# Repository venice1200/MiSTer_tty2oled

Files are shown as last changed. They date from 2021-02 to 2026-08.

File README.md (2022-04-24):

## 👾  👾

*A Display Add-on for the **[MiSTer FPGA]**.*

<br>



<br>
<br>
<br>

<div align = right>
  <div align = center>
  
This project provides both the **Hardware** as well as the <br>
**Software** to drive an **OLED** display with your Arduino <br>
with simple **USB** connection to your **MiSTer** system.
  
  </div>
</div>

<br>
<br>
<br>

---

<div align = center>

  **⸢ [Documentation] ⸥**
  **⸢ [Creating Graphics] ⸥**
  
</div>

---
[][License]
<!----------------------------------------------------------------------------->

[Badge License]: https://img.shields.io/badge/License-GPLv3-blue.svg?style=for-the-badge

[Logo]: Pictures/tty2oled_logo_120x46_blue_black.png?raw=true

[MiSTer FPGA]: https://github.com/MiSTer-devel

[Creating Graphics]: https://github.com/venice1200/MiSTer_tty2oled/wiki/Build_GSC_Gimp
[Documentation]: https://github.com/venice1200/MiSTer_tty2oled/wiki
[License]: LICENSE

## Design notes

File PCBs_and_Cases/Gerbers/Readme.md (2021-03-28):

**Gerber files for producing PCB's.**

PCBWay has a very nice online Gerber viewer:
https://www.pcbway.com/project/OnlineGerberViewer.html

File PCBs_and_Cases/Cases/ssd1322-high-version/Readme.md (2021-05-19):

### This is the "high" version for 3.12" SSD1322 displays

If you want an external case for your tty2oled and have used pin headers to stack the display to the PCB's, this should fit your needs.
Inserting the PCBs or the complete setup into the case is a fiddling thing. To counteract this I've glued the 4 spacer to displays and stacking PCB and was able to use the whole thing very easily.

After inserting screw together case and display/spacer, then put up the lid onto case's back. There're two 3mm holes which may be used to screw case and lid together, but this isn't mandatory and you keep easier access to the ESP :wink:

The ZIP archive presented [here](https://github.com/venice1200/MiSTer_tty2oled/blob/main/PCBs_and_Cases/Cases/ssd1322-high-version/MiSTer_tty2oled.zip) contains ready-to-use STL files for using with 3D printers and other rocket science. But if you're interested in remixing, reworking or customising the case or parts of it, there're [OpenSCAD](https://openscad.org) files for this also included.

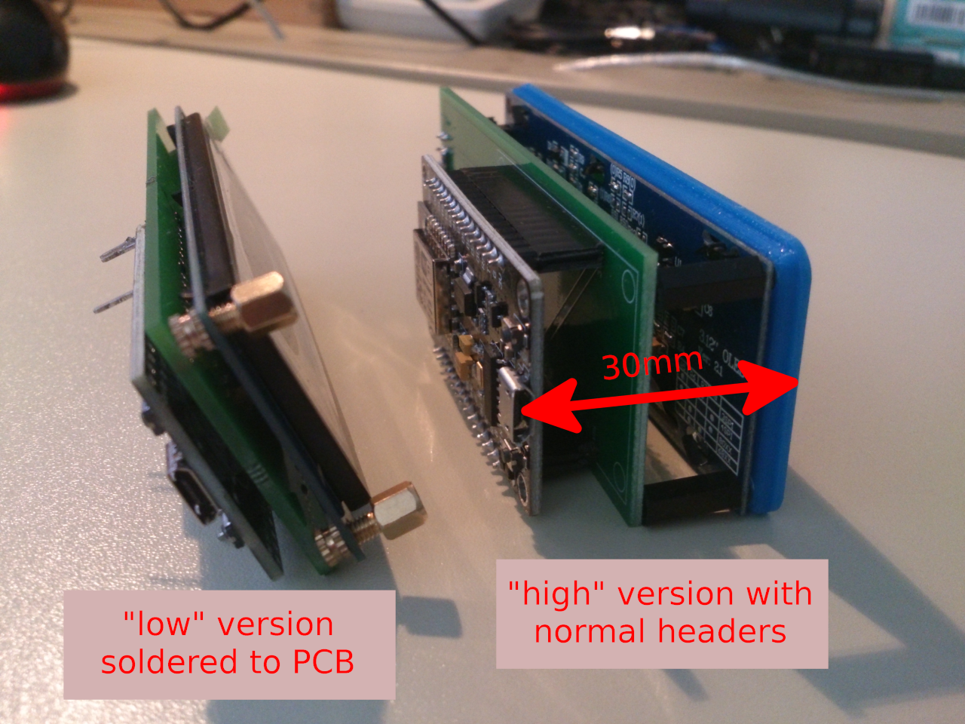
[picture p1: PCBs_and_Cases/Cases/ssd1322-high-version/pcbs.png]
PCBs


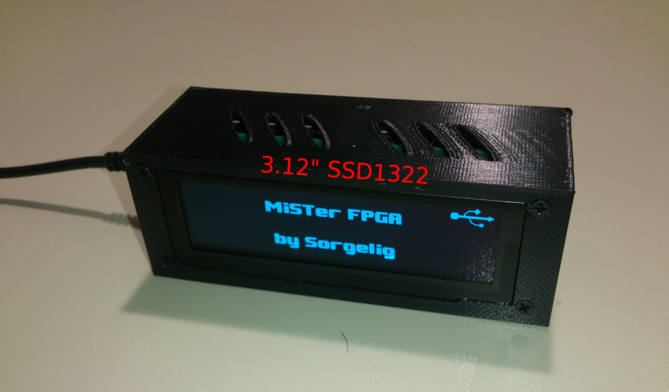
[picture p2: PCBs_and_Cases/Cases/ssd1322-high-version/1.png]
Front


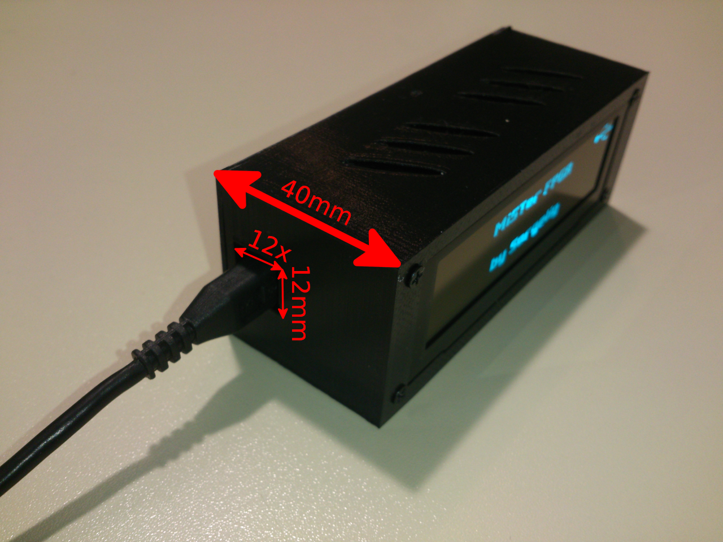
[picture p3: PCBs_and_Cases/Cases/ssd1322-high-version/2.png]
USB side


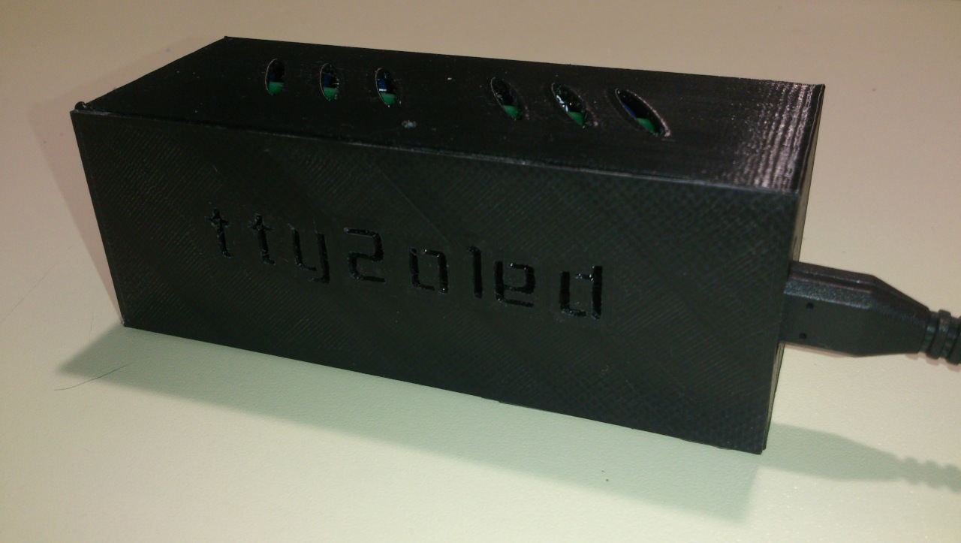
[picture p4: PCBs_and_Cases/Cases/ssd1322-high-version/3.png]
Back


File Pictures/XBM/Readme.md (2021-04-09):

**SD-Version**  
Add your XBM Logo/Picture files to the root folder of your SD Card.  
  
**USB-Version**  
Copy the XBM Logo/Picture files to the `/media/fat/tty2oledpics` folder of your MiSTer's  
or use the new Installer/Updater, see https://github.com/venice1200/MiSTer_tty2oled/wiki/Installation.
  
Name the pictures like the core is named plus .xbm as file extension.  
Example: Lunar Lander's Core Name is "llander", filename must be "llander.xbm".  
The XBM must be 256x64 Pixel for a SSD1322 OLED Display  
  
Examples:  
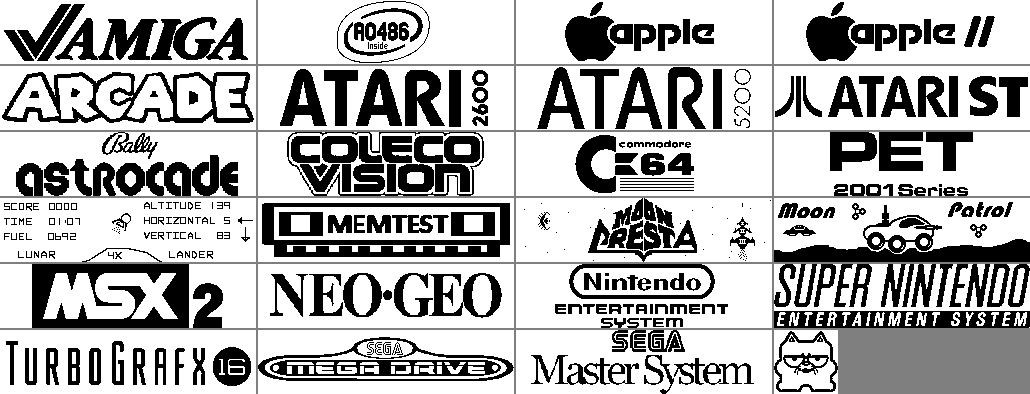
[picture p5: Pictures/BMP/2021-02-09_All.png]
AllInOne


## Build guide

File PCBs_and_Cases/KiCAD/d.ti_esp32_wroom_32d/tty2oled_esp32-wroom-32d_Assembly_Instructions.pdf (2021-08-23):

## Assembly instructions for tty2oled_esp32-wroom-32d case

Required parts:

1x tty2oled_esp32-wroom-32d PCB
1x 3.12“ OLED display (256 x 64 pixel / SSD1322 controller) 1x Case front part
1x Case rear part
4x Standoff (for M3 screws / height: 11 mm)
8x M3 insert nuts (outer diameter: 4.6 mm / length: 6 mm) 4x M3 screws (flat head / length: 20 mm)
4x M3 screws (countersunk head / length: 6 mm)
Step 1: Insert M3 nuts into front and rear part of the case (using a soldering iron).

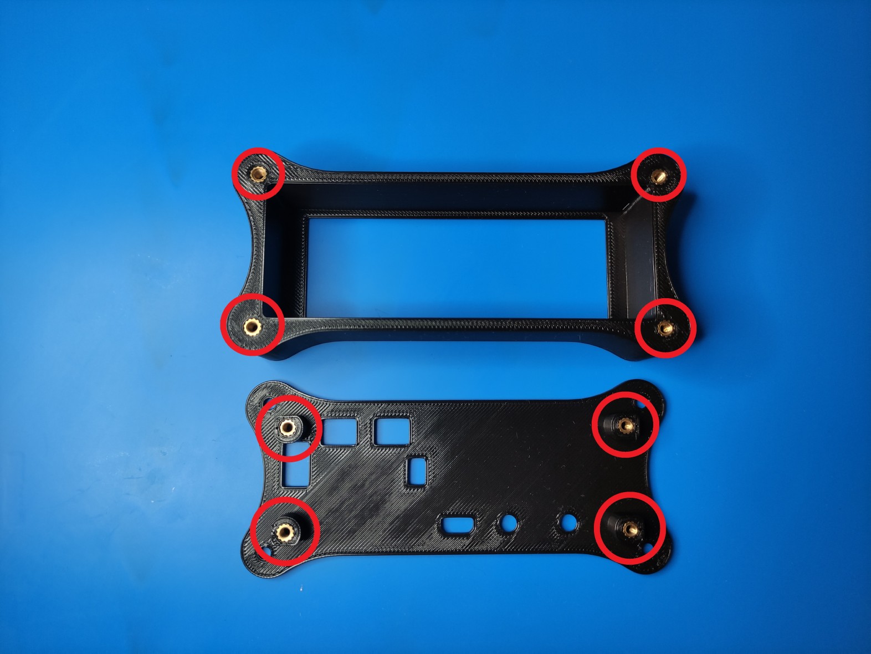
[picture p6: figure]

Step 2: Place tty2oled_esp-wroom-32d PCB on top of the case rear part.
Step 3: Place standoffs on top of tty2oled_esp-wroom-32d PCB.

Step 4: Connect display to tty2oled_esp-wroom-32d PCB.
Step 5: Lock display and tty2oled_esp-wroom-32d PCB into place using M3 flat head screws.

Step 6: Put case rear part onto front part.
Step 7: Lock case rear part to front part using M3 countersunk head screws.

Step 8: Done.

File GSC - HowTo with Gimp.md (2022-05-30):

------------------------ ENGLISH ------------------------

Have a look for a banner or logo of the desired picture which roughly could
be scaled down to 256\*64 pixels without losing too much details and contrast.
Start Gimp, load or insert the found picture and

- if there is a transparent layer, remove it by /Layer/Transparency/Remove Alpha Channel
- /Colours/Desaturate/Colour to Grey
~~- /Colours/Invert~~ Let image2lcd do the invert
- /Image/Mode/Indexed/Generate optimum palette (16 Colours)
- /Image/Scale Image/256\*64 if possible. It might be needful to resize
  the picture non-proportional. Otherwise resize to 256\*Y or X\*64 and
- use /Image/Canvas Size afterwards to move the whole thing so that it fits
- /File/Export as/ and save your work as GIF
- Start image2lcd, load your GIF, check *Reverse color* and save the result as \*.C file
  without "head data"
- Edit the created \*.C file and replace the line
  "const unsigned char gImage_x[8192]" by

//  
//  
const unsigned char _bits[8192] PROGMEM = {

Done.
------------------------ ------ ------------------------
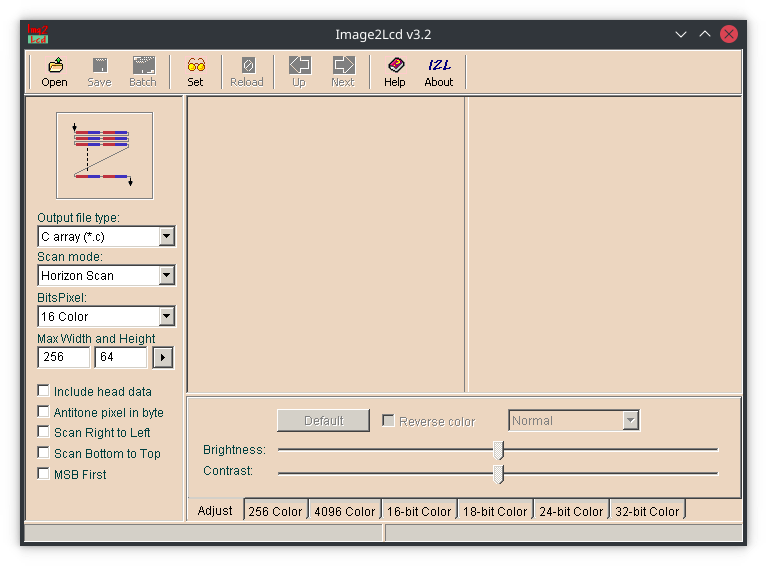
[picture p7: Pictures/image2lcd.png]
image2lcd settings

------------------------ ------ ------------------------

------------------------ GERMAN ------------------------

Ein Banner o.ä. suchen, welches sich Pi\*Daumen auf ca. 256\*64 Pixel skalieren
lässt. Hatt man denn eines gefunden, ist die weitere Vorgehensweise wie folgt:

- Falls eine transparente Ebene vorhanden ist: /Ebene/Transparenz/Alphakanal
  entfernen
- /Farben/Entsättigen/Grau einfärben
~~- /Farben/Invertieren~~ Besser durch image2lcd invertieren lassen
- /Bild/Modus/Indiziert/Optimale Palette (16 Farben)
- /Bild/Bild skalieren/256\*64 sofern möglich. Manchmal reicht es auch, einfach
  nicht-proportional zu skalieren. Ansonsten auf 256\*Y oder X\*64 skalieren und
- per /Bild/Leinwandgröße das ganze zurecht rücken, so dass es passt
- /Datei/Exportieren nach/ als BMP oder GIF speichern
- Das exportierte Bild in image2lcd laden, *Reverse color* anhaken und als \*.C wieder speichern
  (ohne "head data")
- Im \*.C Export die Zeile "const unsigned char gImage_x[8192]" entfernen und
  durch ersetzen durch:

//  
//  
const unsigned char _bits[8192] PROGMEM = {

Fertig.

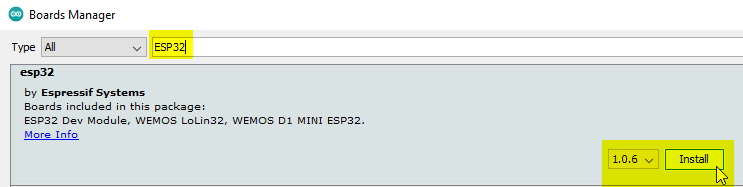
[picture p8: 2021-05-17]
Pictures/HowTo/tty2oled_arduino_03_board_02_ESP32.png

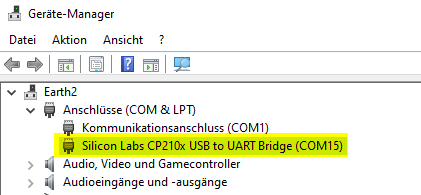
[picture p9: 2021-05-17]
Pictures/HowTo/tty2oled_arduino_10_windows_01_device.png

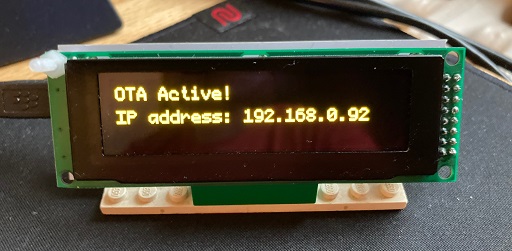
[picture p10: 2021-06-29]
Pictures/HowTo/tty2oled_arduino_14_BasicOTA_03.jpg

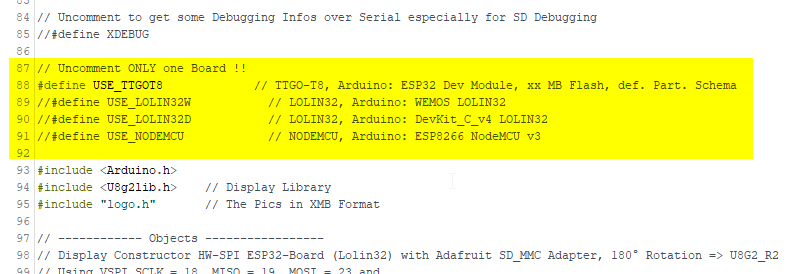
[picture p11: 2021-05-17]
Pictures/HowTo/tty2oled_arduino_07_sketch_01_uncomment_board.png

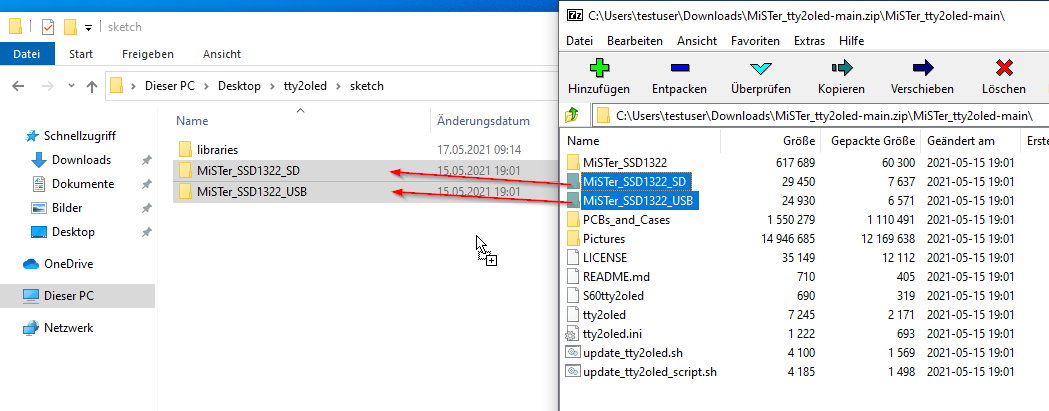
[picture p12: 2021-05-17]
Pictures/HowTo/tty2oled_arduino_05_sketch_01_extract.png

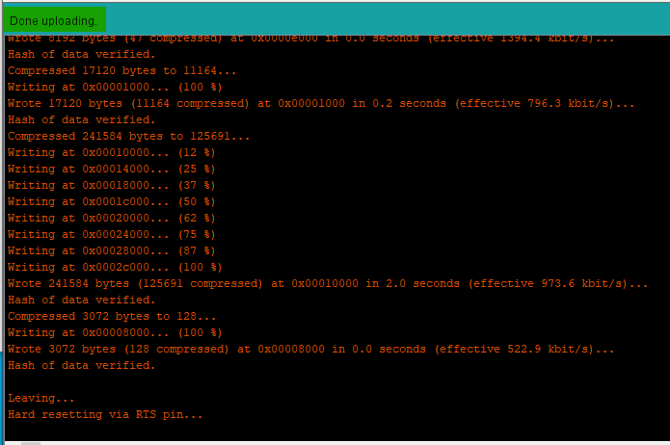
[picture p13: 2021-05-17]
Pictures/HowTo/tty2oled_arduino_12_sketch_03_uploaded.png

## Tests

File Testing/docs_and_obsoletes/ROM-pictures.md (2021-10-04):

Überlegungen zu den neuen ROM-Pictures

Relevant neben /tmp/CORENAME sind /tmp/CURRENTPATH und /tmp/FULLPATH. In CURRENTPATH steht die gestartete ROM-Datei des Cores und in FULLPATH der Pfad zum gestarteten ROM.

Da viele ROMs dieselbe Fileextension haben wie schon andere Cores/ROMs und Dateinamen der ROMs unzuverlässig sind, scheinen Dateiprüfsummen unausweislich.  
Es gibt für viele/alle Emulatoren ROM-Sets, aus denen man entweder eine bereits vorhandene Prüfsummendatei entnehmen (z.B. MAME) oder ggf. eine eigene generieren könnte. Aufbau der Prüfsummendatei für uns ähnlich wie gehabt:

Dateiname des Bilds immer klein ohne Extension, Unterstrich statt Leerzeichen:
__sha1sum[space]Dateiname_des_Bilds_ohne_Extension__
e4134a3b4a065c856802bc935c12fa7e9868110a battlezone  
2bbc124cead9aa49b364268735dad8cb1eb6594f james_bond_007  

(keine Extension weil **first find fits**, also gsc -> xbm -> text)

Parallel dazu einen User-eigenen Prüfsummenteil für persönliche Vorlieben, Homebrews, Hacks .....

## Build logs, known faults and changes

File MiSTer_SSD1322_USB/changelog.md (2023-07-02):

*************************** tty2oled Arduino-FW Changelog ***********************

  2023-07-02
  -Release to Stable

..2023-04-27
  -Cosmetics

  2023-04-20/2023-03-16
  -Add Command CMDSTTYACK to (set) enable(1)/disable(0) sending "ttyack". Enabled by default.
   Using no Command Delay (cDelay) if "ttyack" is not sent.

  2023-01-08
  -Add Boolean "runsTesting"

  2022-12-09..2023-01-07
  -Add more "hasXX"

  2022-12-08
  -Change 8266 NodeMCU Tilt Pin 16 (D0) to Pin 10 (SD3) to prevent false Rotation detection

  2022-11-27
  -Switch dtiv Version handling from "EEPROM" to "Preferences"

  2022-11-23
  -Removed unused Board Types

  2022-11-12..13
  -Add Suport for ESP32-S3 (ESP32-S3-DevKitC-1)
  -Removed OTA Support
  -Add EEPROM Support for d.ti Boards (IDE: ESP32* Dev Module)

  2022-10-30
  ***** Release to stable 221030 ******

  2022-10-24
  -Change Picture Array logoBin from "malloc" to "normal" defined type.

  2022-10-20
  -Add randomly chosen animated ScreenSaver after Corechange

  2022-10-15
  -Add short delay after Rotation-Pin Initialization (try to prevent false Rotation detection on 8266)
  -Add ScreenSaver Flying Toasters by Phillip Burgess/Adafruit
   https://learn.adafruit.com/animated-flying-toaster-oled-jewelry/code (MIT License) 
   Screensaver Bits: Bit 0=tty2oled Logo (Value 1), 1=MiSTer Logo (2), 2=Core Logo (4), 3=Time (8), 4=Date (16), 5=Stars (32), 6=Toast (64)

  2022-10-14
  -Changed filename logo.h to bitmaps.h
  
  2022-10-12
  -Modifying "Stars", adding Star-Depth-Color calculation

  2022-10-09
  ***** Release to stable 221009 ******

  2202-10-07
  -Fix for 8266 which don't get the Starfield Screensaver to prevent stability issues

  2022-09-30
  -Add the StarField Simulation as ScreenSaver
   Code from https://github.com/sinoia/oled-starfield (MIT License) 
   8266 must run at 160MHz!
   Screensaver Bits: Bit 0=tty2oled Logo (Value 1), 1=MiSTer Logo (=Value 2), 2=Core Logo (Value 4), 3=Time (Value 8), 4=Date (Value 16), 5=Stars (Value32)

  2022-09-25..27
  -New Command "CMDSWSAVER,[0/1]" for just Switching the Screensaver on/off
  -Workaround for the detection of PCA9536 = d.ti Board v1.2
  
  2022-09-02
  -New functions "oled_showcenterredtext" and "oled_setfont"

  2022-09-01
  -More usage of "dtiv"

  2022-08-26..28
  -New Command "CMDSHSYSHW" shows Hardware & Software Infos on Screen

  2022-09-18
  -Shorten the Date Format for the Screensaver. e.g. "19. September 2022" => "19-Sep-22".

  2022-08-07..12
  -Add RGB LED to Startup Screen (d.ti Board 1.2)
  -New Variable "dtiv" showing d.ti Board Revisions: 11=1.1 12=1.2...

  2022-08-23
  -Replace some "if (pcaAvail)" with "if (dtiv==12)"

  2022-07-31
  -SSD1322 Minor change
  -New Option "XOTA" for disable/enable the OTA functionality, Sketch consumption 65%->28%

  2022-07-23 
  ***** Release ***** to stable 220723 (based on 220714T)

  2022-07-12..14
  -Introduce ScreenSaver "Screens" which can be selected separatly (bitwise)
   Bit 0=tty2oled Logo (Value 1), 1=MiSTer Logo (=Value 2), 2=Core Logo (Value 4), 3=Time (Value 8), 4=Date (Value 16)
   Examples: 12=4+8=Core+Time, 5=1+4=tty2oled+Core, 13=1+4+8=tty2oled+Core+Time

  2022-07-09
  -Minor Update to make the Sketch compatible to ESP32 Board-Pack v2.0.4

  2022-07-08 -OBSOLETE- see 2022-07-12
  -Change ScreensaverColor to ScreeensaverMode
   Modes: 1: Show tty2oled Logo
          2: Show tty2oled Logo, Mister Logo
          3: Show tty2oled Logo, Mister Logo, Core Logo
          4: Show tty2oled Logo, Mister Logo, Core Logo, Time
          5: Show tty2oled Logo, Mister Logo, Core Logo, Time & Date

  2022-07-06
  -Adding two new fonts u8g2_font_commodore64_tr and u8g2_font_8bitclassic_tf

  2022-06-08
  -Note: Use U8g2_for_Adafruit_GFX setForegroundColor and setBackgroundColor together for inverted text
   See: https://github.com/olikraus/U8g2_for_Adafruit_GFX#command-reference

  2022-06-02
  -Add Function Prototypes for C++ Compatibilty

  2022-05-21
  -Only Cosmetics

  2022-05-07
  ** Release to stable**
  -Fix CMDPNOTE/CMDPTONE
  -Add CMDSHTIME
  -A lot Cosmetics
  -Lib Update: ESP32 Package 2.0.1 -> 2.0.3
  -Lib Update: Adafruit GFX 1.10.14 -> 1.11.1

  2022-04-28
  -Remove CMDSTEMP command and temnperature loop
  -Add CMDSHTEMP Command, show only once the actual MIC184 Temperature, for DTI Boards only

  2022-04-22
  -Command CMDSETTIME can be called by all MCU's but only the ESP32 is setting his internal RTC

  2022-04-18
  -Add Time to ScreenSaver but only if Time was set before, and only for ESP32

  2022-04-17
  -Add Code for new Commadn CMDSETTIME (stolen from tty2tft)
  -Add CMDNULL (Test) Command, for Troubleshooting and ACK Testing.
  
  2022-04-16
  -Fix CMDPNOTE/CMDPTONE Bug if Parameter is missing

  2022-04-10..13
  -Add Command "CMDSECD,[value]" to set the Command Delay
  -Add Command "CMDSHCD" to show the actual Command Delay "On Screen" (for Debugging)
  -Set cDelay for ESPDEV=15, Lolin32=60, 8266=60 after some manual tests with MiSTer SAM

  2022-04-07
  -Testing without "serial.flush" after "ttyack;"
  
  2022-04-07
  -Renamed Command CMDPTONE to CMDPNOTE
   >> CMDPNOTE,C,4,150,30,C,4,160,30,C,4,150,30,F,4,150,30,C,4,150,30  
  -Renamed Command CMDPFREQ to CMDPTONE

  2022-04-05
  -Wemos Lolin 32 Profile: #define cDelay 100 fixes MiSTer SAM issues with waitforack

  2022-04-01
  -Consolidate CMDSSCP/CMDSSCP2 and oled_showSmallCorePicture/oled_showSmallCorePictureV2

  2022-03-31
  ** Release **

  2022-03-23
  -Change cDelay from Variable to MCU dependent #define Value
   Fixes a response issue using "waitforack" and MiSTer_SAM with NodeMCU 8266

  2022-03-19
  -Screensaver Mod, use avarage of 2x2 Pixels for the small GSC Picture

  2022-03-16
  -Screensaver Mod, use 1/4 size Core Picture for the ScreenSaver
  -New Command CMDSSCP

  2022-03-02
  -Use more PicType "NONE" (Cosmetics)

  2022-02-17
  -Change minimum SceeenSaver Intervall from 10s to 5s

  2022-02-09 
  ** Release to Stable **

  2022-02-07
  -Modified Calculation ScreenSaverLogoTime
   First Screensaver shown now after ScreenSaverLogoTime-ScreenSaverInterval+ScreenSaverInterval

  2022-02-06
  -Change Command CMDSAVER
   CMDSAVER,Mode/Color, Interval, LogoTime
   Mode/Color: 0=Off, 1..15=On/Color, Interval: 10..600 Seconds, LogoTime: 10..600 Seconds

  2022-02-05
  -Add Command CMDSAVER to enable Screensaver
   CMDSAVER,Mode/Color, Interval
   Mode/Color: 0=Off, 1..15=On/Color, Interval: 10..600 Seconds

  2022-01-29..30
  -Enhanced Support for d.ti Board Rev 1.2
  -Modded Command CMDULED supporting d.ti Board v1.2
   d.ti Board v1.1 CMDULED,[0,1] User LED Off/On
   d.ti Board v1.2 CMDULED,[0,1..255] WS2812B User LED Off/On with Color (HSV Colors; Hue = Command Parameter, Saturation & Value = 255)
  -Add Command CMDPLED for d.ti Board v1.2
   CMDPLED,[0,1] Switch Power LED Off/On
  -Add Command CMDPTONE for d.ti Board v1.2
   CMDPTONE,[Note,Octave,Duration,Pause],[Note,Octave,Duration,Pause]... play Note/Tone using the Buzzer.
   CMDPTONE,C,4,150,30,C,4,160,30,C,4,150,30,F,4,150,30,C,4,150,30
  -Add Command CMDPFREQ for d.ti Board v1.2
   CMDPFRQ,[Frequency,Duration,Pause],[Frequency,Duration,Pause]... play Frequency using the Buzzer.

  2022-01-23
  -Add Basic Support for d.ti Board Rev 1.2 and the included WS2812B LED, Buzzer, Power(off)LED
  -Piezo Buzzer Tone Examples https://makeabilitylab.github.io/physcomp/esp32/tone.html
  -FastLED https://github.com/FastLED/FastLED/wiki, https://www.youtube.com/watch?v=FQpXStjJ4Vc

  2022-01-05
  -Cleanup unused vars, adding some cast operators

  2022-01-04
  ** Release to stable**
  -New Command CMDCLSWU
   Clear Display Buffer without Display Update (like CMDCLS) 
  -Send "ttyrdy;" after Display Start/Setup is done

  2021-12-16
  -Changed Command "CMDCOR"
   Adding optional Effect Parameter "t" after Corename, Example "CMDCOR,llander,19"
   t= -1:Random Effect, 0=No Effect, >1=see Effect List
  -Changed Command "CMDSPIC"
   Adding optional Effect Parameter "t" after Command, Example "CMDSPIC,19"
   t= -1:Random Effect, 0=No Effect, >1=see Effect List
  -Changed Command "CMDCLST"
   t= -1:Random Effect, 0=No Effect, >1=see Effect List

  2021-12-14
  -New Command "CMDCLST,t,c" (t=transition, c=color (0..15))
   Clear the Display Screen with transition and given color

  2021-12-07
  -ESP32DEV only: Adding PCA9536 availabilty check

  2021-11-29..12-06
  -New Effects 15-19 (Fade in from center to...)
  -New Effects 20 (Slightly Clockwise), 21 (Shaft), 22 (Waterfall), 23 (Chess Squares)

  2021-11-26
  ** Release ** See forums post next to https://misterfpga.org/viewtopic.php?p=38195#p38195 

  2021-11-22
  -Cleanup not needed "NA/NN" Texts

  2021-11-16
  -Removed Options for XTILT and XDTI. We use now software mechanism for determination of Hardware
  -MIC184 only available for ARDUINO_ESP32_DEV/USE_ESP32DEV Hardware and only if MIC is detected via i2c
  -Tilt available for all Hardware Platforms, ESP8266 Tilt Pin = Pin16

  2021-11-15
  -Changed Option USE_TTGOT8=USE_ESP32DEV

  2021-11-14
  -New Command "CMDHWINF"
   Send HW Info back to the MiSTer/CMD-Sender. Useful for ESP Firmware Updates.
   Currently: "HWESP32DE"=TTGO-T8 ESP32, "HWLOLIN32"=Lolin&DevKit ESP32, "HWESP8266"=ESP8266, "HWDTIPCB0"=d.ti Board ESP32

  2021-11-11
  -MIC184 uses now the Library MIC184 (modified LM75 Library)
  -New Command "CMDTZONE,z" for d.ti Board only!
   Set the Temperature Zone for the MIC184. z=0 Internal Zone, z=1 Remote Zone.

  2021-11-04/07
  -New Picture Slide-In Effects (11..14) and some effect speed adjustments

  2021-10-28
  -Adding Bool-Variable "startScreenActive"
  -Renamed function "oled_mistertext" to "oled_showStartScreen"

  2021-10-27
  -d.ti Board only: Actualize Temperature on plain boot screen if activated

  2021-10-22
  -d.ti Board only: If you sent the Text "TEP184" via Command "CMDTEXT" the Text will be replaced with the Temperature Sensor Value including "°C"

  2021-10-20
  -Added 7 Segment Font (Font 8)

  2021-10-12
  -Release "Greyscale Mode"

  2021-10-11
  -Adding Command "CMDSTEMP" for the d.ti Board (Option XDTI)
   If you send this command the Display shows and refreshs the Temperature as long as no other Commands are sent.

  2021-10-08
  -Adding Library "U8G2 for Adafruit GFX" for better Text Support
  -Adding hidden Text write and Geometric draw Modes to the Text and Geo Commands
   Font or Geo Value +100 write or draw the content only to the Display buffer without displaying it
   Good for cleaning up Display content
  -Text Command got Background Color Variable
   Write Text with given Font Color (c) and Background Color (b)
  -Adding Command "CMDDUPD"
   Update Display content (write buffer to Display)

  2021-10-01
  -Renamed Otion XMIC184 to XDTI
  -Adding USER_LED (Pin 19) for the d.ti Board (Option XDTI) 
  -Adding Command "CMDULED,0/1" for the d.ti Board (Option XDTI)

  2021-09-25/26
  -Adding Effects 1-10
  -Adding DisplayOn/Off Commands
  -Adding Geo Command, the handling is slightyl slightyl different to the U8G2 Version
  -Adding Text Command with 5 Font's, the handling is slightyl different to the U8G2 Version

  -- G R A Y S C A L E  E D I T I O N --

  2021-09-19
  -First Grayscale Test based on MiSTer_SSD1322_USB_Testing

  2021-09-10
  -Add "#define XMIC184"
   Uncomment this Option to activate the MIC184 Temperatur-Sensor included on d.ti's PCB.
   This function uses the Library "eHaJo_LM75" which is available in the Library Manager.

  2021-09-07
  -Add "#define XTILT"
   Uncomment this Option to activate Autorotation.
   Use tilt sensor connected to PIN 15 (SPI_0_CS) and GND.
   This function uses the Library "Bounce2" which is available in the Library Manager.

  2021-08-23..26
  -Moved Startscreen-Text into "defines"
  -Add "#define XSENDACK"
   Uncomment this Option to enable the Handshake with the MiSTer Daemon. !! You need the Daemon from testing !!
  -Add "#define XLOGO"
   Uncomment this Option to get the tty2oled Logo shown on Startscreen instead of the Starttext
  -Change Variable Name "newCore" into "newCommand"

  2021-08-15/16
  -Separate the "Read and Draw Picture" function into two functions
  -New Command "CMDSPIC" which just show the actual loaded Picture (SHOWPIC).
  -New String Variable "actCorename" containing the actual Corename
  -New Command "CMDSNAM" which just show the actual Corename as text (SHOWNAME).
  -New Command "CMDAPD,[corename]" which is just for sending Picture Data, nothing more (Attention Picture Data).
  -!Remove old Command Mode (att, CORECHANGE, CONTRAST, TEXTOUTXY, GEOOUTXY) so you need to use an actual Daemon

  2021-08-10
  -Reactivate System "#define USE_xxxx" set by Arduino's Board selection (Auto Mode) 
   or by uncommenting only the needed "#define USEe_XXX" for your Hardware
  -Add #define "XROTATE", uncomment it for an 180° Rotated Display.

  2021-08-07
  -New & smaller USB Icon.

  2021-08-03
  -Some of the included Logo's miss their U8X8_PROGMEM.

  2021-07-12
  -New Command to set the Font Direction. 
   "CMDFOD,[Parameter]", Parameter Format "d", d: 0=Left to Right (0°, default), 1=Top to Down (90°), 2=Right to Left (180°), 3=Down to Top (270°)

  2021-07-18 (Testing)
  -Trying Handshake with the MiSTer Daemon by sending "ttyack;" (with delimiter) after each processed command.
   !! But this need a very little delay of [cDelay]ms before "ttyack" could be send. => Need more testing !!
   In tty2oled.ini the TTYPARAM Parameter needs "-echo"

  2021-07-12
  -Combine the two separate LogoDrawing functions (usb2oled_readndrawlogo/usb2oled_readndrawlogo2) into one (usb2oled_readndrawlogo2)

  2021-07-11
  -Some more yield() fixes for ESP8266
  -Bugfix Effekt 10 (Diagonal)

  2021-07-10
  -Add Serial.flush to "Setup" to clear the transmit buffer, see https://misterfpga.org/viewtopic.php?p=29703#p29703

  2021-07-09
  -Some yield() fixes for ESP8266

  2021-07-07/08
  -New Command "CMDTEST" which just show an fullscreen test-picture
  -Count amount of transferred picture bytes and if it doesn't match show an error picture
  -Change Command processing from "if (newCommand!=oldCore)" to "if (updateDisplay)" to prevent a blank screen if multiple data packs are sent.
  -Add (Micro Font) Build Version to Start Screen

  2021-06-30
  -New Command "CMDROT"
   "CMDROT,[Parameter]" Set Display Rotation (0=180° (My Standard), 1=0 degrees) Rotation after Start
   You will see the Command Result after the next Write/Draw Command.

  2021-06-24
  -Changed location of the "yield()" Command which is needed for 8266 NodeMCU

  2021-06-22 
  -New Command Mode (Testing)
   "CMDCLS"
   "CMDSORG"
   "CMDBYE"
   "CMCOR,[Corename]"
   "CMDCON,[Contrast]"
   "CMDTXT,[Parameter]"   Text-Ouput,          Parameter-Format = "f,c,x,y,[Text]
   "CMDGEO,[Parmeter]"    Geometric-Output,    Parameter Format = "g,c,x,y,i,j,k"
   "CMDRESET" 
   "CMDENOTA"
   "CMDOFF,[Parameter]"   Set Power Save Mode, 0=Disabled/Display ON (default), 1=Enabled/Display OFF
  2021-06-19
  -Adding "GEOOUTXY" Command
   Drawing/Clearing Geometric Figures (Pixel, Line, Frame, Box (Filled Frame), Circle, Disc (Filled Circle), Ellipse, Filled Ellipse, Rounded Frame, Rounded Box)
   Example/Command Order: 
   1: echo "att" > /dev/ttyUSB0
   2: echo "GEOOUTXY" > /dev/ttyUSB0
   Draw Example
   3: echo "3,0,20,10,30,20,0" > /dev/ttyUSB0 (Draw Frame starting at x=20, y=10 with width 30 and height=20)
   Clear Example
   3: echo "4,1,20,10,30,20,0" > /dev/ttyUSB0 (Clear Box starting at x=20, y=10 with width 30 and height=20)

   The Command-Parameter Format is "g,c,x,y,i,j,k"
   g = Geometric Type 1..10
   c = Draw Color 0=Clear, 1=Draw, 2=XOR/Invert Pixel
   x = X-Position 0..255
   y = Y-Position 0..63
   i = Parameter 1 (Depends on Geometric)
   j = Parameter 2 (Depends on Geometric)
   k = Parameter 3 (Depends on Geometric)
   
   Geometric Type            Parameter needed                     Link
   1:  Pixel                 need x,y                             https://github.com/olikraus/u8g2/wiki/u8g2reference#drawpixel
   2:  Line                  need x,y,i=x1, j=y1                  https://github.com/olikraus/u8g2/wiki/u8g2reference#drawline
   3:  Frame                 need x,y,i=width,j=height            https://github.com/olikraus/u8g2/wiki/u8g2reference#drawframe
   4:  Box (Filled Frame)    need x,y,i=width,j=height            https://github.com/olikraus/u8g2/wiki/u8g2reference#drawbox
   5:  Circle                need x,y,i=radius                    https://github.com/olikraus/u8g2/wiki/u8g2reference#drawcircle
   6:  Disc (Filled Circle)  need x,y,i=radius                    https://github.com/olikraus/u8g2/wiki/u8g2reference#drawdisc
   7:  Ellipse               need x,y,i=radiusx,j=radiusy         https://github.com/olikraus/u8g2/wiki/u8g2reference#drawellipse
   8:  Filled Ellipse        need x,y,i=radiusx,j=radiusy         https://github.com/olikraus/u8g2/wiki/u8g2reference#drawfilledellipse
   9:  Rounded Frame         need x,y,i=width,j=height,k=radius   https://github.com/olikraus/u8g2/wiki/u8g2reference#drawrframe
   10: Rounded Box           need x,y,i=width,j=height,k=radius   https://github.com/olikraus/u8g2/wiki/u8g2reference#drawrbox

  -Add "CMDTXT,[Parameter]" Format to "f,c,x,y,[Text]"
   f = Font Type 0.. (see Font List above)
   c = Draw Color 0=Clear, 1=Draw, 2=XOR/Invert Pixel
   x = X-Position 0..255
   y = Y-Position 0..63 
   [Text] = Text to Draw

  2021-06-18
  -BasicOTA only for ESP32 <= TESTING

  2021-06-18
  -Change MALLOC for Picture Data Memory Allocation into Setup for more stabilty. <= TESTING
  -Disabled "Snake" Transition, need too much time.
  -Changed "TEXTOUTXY" Command-Parameter Format to "x,y,f,[Text]"
   x = X-Position 0..255
   y = Y-Position 0..63 
   f = Font Type 0.. (see Font List above)
   Better calculation using "indexof".
   Found here: https://forum.arduino.cc/t/how-to-parse-arduino-string-with-different-delimiters/324653/3

  2021-06-17 
  -Adding Fonts for "TEXTOUTXY"
   https://github.com/olikraus/u8g2/wiki/fntlistall
   f:  Font Type            Width x Height, Size for Character A
   0:  u8g2_font_luBS08_tf (20x12, 8 Pixel A, Transparent)
   1:  u8g2_font_luBS10_tf (26x15, 10 Pixel A, Transparent)
   2:  u8g2_font_luBS14_tf (35x22, 14 Pixel A, Transparent)
   3:  u8g2_font_luBS18_tf (44x28, 18 Pixel A, Transparent)
   4:  u8g2_font_luBS24_tf (61x40, 24 Pixel A, Transparent)
   5:  u8g2_font_profont12_mf (6x12, 8 Pixel A, Non-Transparent)
   6:  u8g2_font_profont17_mf (9x17, 11 Pixel A, Non-Transparent)
   7:  u8g2_font_profont22_mf (12x22, 14 Pixel A, Non-Transparent)
   8:  u8g2_font_profont29_mf (16x29, 19 Pixel A, Non-Transparent)
   9:  u8g2_font_open_iconic_all_2x_t (16x16 Icons, Transparent)
   10: u8g2_font_lucasarts_scumm_subtitle_o_tf (Nice 12 Pixel Font, Transparent)

  2021-06-14
  -Adding "TEXTOUTXY" Command
   With this additional function you can send text to the Display without using the tty2oled scripts.
   ! The Serial Interface needs to be correctly configured !
   The Command-Parameter Format is "xxx,yy,f,[Text]" (! Changed see 2021-06-18)
   xxx = 3 Digits X-Position 000..255
   yy  = 2 Digits Y-Position 00..63 
   f   = Font Type
   Tip: Use the command "cls" to clear the screen => echo "cls" > /dev/ttyUSB01
   Example/Command Order: 
   1: echo "att" > /dev/ttyUSB0
   2: echo "TEXTOUTXY" > /dev/ttyUSB0
   3: echo "010,10,1,Text Out" > /dev/ttyUSB0

  2021-05-24
  -Trying to detect the Board chosen in the Arduino IDE (ESP32 Dev Module, WEMOS LOLIN32 or NODEMCU 8266) and set the Display config.
   No need to set the Board manually in the Sketch.
   But without the correct Board you get Compiler Errors.

  2021-05-22
  -Device CleanUp 

  2021-05-05
  -Add an Option to receive the Contrast Level from the MiSTer
   At First MiSTer needs to send "att"
   As Second MiSTer needs to send "CONTRAST"
   As Third MiSTer needs to send "[Contrast Value 0..255]"

  2021-04-??
  -Add "Set Contrast" to the Code by "ojaksch"

  2021-03-29
  -USB Version Based on SD Version
   Adding USB functionality from "ojaksch" (Many Thanks) and removed SD Stuff.
   Receive Picture-Data via Serial connection instead of the Corename from the MiSTer.
   Speed up Serial Interface to 115200
   Show a small "USB-Icon" on Startup Screen

  -Using #ifdef...#endif for my different HW-Configs (LOLIN32/TTGOT8)
   Choose ONLY one USE_xxxx Board definition at the beggining of the Sketch
  -Adding more Debug Infos

  2021-03-14
  -Using/Testing SD_MMC Mode (Should not matter in case of SD Access speed because of too small files. 
   Board 1: Lolin32 Board with Adafruit Micro SD SPI/SDIO Adapter. SD Access possible using SPI or 1/4.Bit SD Bus Mode.
   Board 2: TTGO_T8 v1.7.1 with integrated SD Slot. SD Access possible using SPI or 1.Bit SD Bus Mode.
   
   SD Adapter Excample Connections:
   SD Card | ESP32 4-Bit | ESP32 1-Bit (TTGO-T8)
   ----------------------------------------------
     D0       2              2
     D1       4              
     D2       12             
     D3       13             13
     CLK      14             14
     CMD      15             15
     VSS      GND            GND
     VDD      3.3V           3.3V

  2021-03-07
  -Adding some Menu Effects
  -Code cleanup

  2021-03-06
  -Adding some Menu Effects
  -Code cleanup

  2021-02-16 (not released)
  -Make it more Universal 
   Add DispLineBytes , using more DispHeight & DispWidth instead of fixed Values

  2021-02-20/21
  -Using the Effects for all Picture/Logo Transistions (not only for the Menu)
  -"MENU" Picture moved from Code to the SD, makes it easier to change (if you like).
  -Modified Text Position calculation (see U8G2 Documentation for Details). 
   Change text reference position from TOP to BASELINE.
   Using now "getAscent" instead of "getMaxCharHeight" for Text Y-Position calculation.
  -Show a small "SD-Icon" on Startup Screen instead of the "dot" if SD Card was detected.

  2021-02-12
  -Adding some Menu Effects

  2021-02-11
  -Trying to make it more universal in case of used display sizes. Using more "DispHeight" and "DispWidth" instead of fixed values.
  2021-02
  -Change serial Speed to 57600
  -Adding SD Support for ESP32 using an dedicated SPI Interface
   Use now an TTGO-T8  ESP32 with integrated SD Micro Slot https://github.com/LilyGO/TTGO-T8-ESP32 .output
   All Logos or Picture have to be 256x64 Pixel (Display Size) in XBM Format.
   Place the Pictures to the root of the FAT or FAT32 formatted SD Card an give them the name like the core is named with extension (Lunar Lander = llander.xbm).
   Use Code from "XBM Read from FS" from https://github.com/lbernstone/eyes
  -Add "#define XDEBUG" for Debugging, can be Uncommented for more Infos over Serial

=====================================================================================
=====================================================================================
ToDo
-Everything I forgot

Effect List (2021/12)
01 Fade In Left to Right
02 Fade In Top to Bottom
03 Fade In Right to left
04 Fade In Bottom to Top 
05 Fade In Even Line Left to Right / Odd Line Right to Left
06 Fade In Top Part Left to Right / Bottom Part Right to Left
07 Fade In Four Parts Left to Right to Left to Right...
08 Fade In 4 Parts, Top-Left => Bottom-Right => Top-Right => Bottom-Left
09 Fade In Particle Effect
10 Fade In Left to Right Diagonally
11 Slide In left to right
12 Slide In Top to Bottom
13 Slide In Right to left
14 Slide In Bottom to Top
15 Fade In Top and Bottom to Middle
16 Fade In Left and Right to Middle
17 Fade In Middle to Top and Bottom
18 Fade In Middle to Left and Right
19 Fade In Warp, Middle to Left, Right, Top and Bottom
20 Fade In Slightly Clockwise
21 Fade In Shaft
22 Fade In Waterfall
23 Fade In Chess
24 WIP

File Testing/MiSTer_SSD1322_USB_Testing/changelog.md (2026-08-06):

*************************** tty2oled Arduino-FW Changelog ***********************
Build Enviroment 29.7.2026
--------------------------
Arduino IDE 2.3.10

Downloadable libs/package from the Arduino IDE
ESP32 3.3.11
FastLed 3.10.5
U8g2_for_Adafruit_GFX 1.8.0
Adafruit GFX 1.12.6
Bounce2 2.71
ESP32Time 2.0.6

Manual installed libs
MIC184 https://github.com/venice1200/MIC184_Temperature_Sensor
SSD1322_for_Adafruit_GFX https://github.com/venice1200/SSD1322_for_Adafruit_GFX

ESP32 DevModule Build
Sketch uses 565151 bytes (43%) of program storage space. Maximum is 1310720 bytes.
Global variables use 51488 bytes (15%) of dynamic memory, leaving 276192 bytes for local variables. Maximum is 327680 bytes.

ESP32S3 DevModule Build
Sketch uses 584647 bytes (44%) of program storage space. Maximum is 1310720 bytes.
Global variables use 49572 bytes (15%) of dynamic memory, leaving 278108 bytes for local variables. Maximum is 327680 bytes.

=================================================================================

  2026-07-29...08-06
  -Bump Version for Testing Libraries, Board Packages and IDE Updates
  -Added "Serial.setRxBufferSize(1024)" in setup for ESP32 Devices, taken from Arrghus8 fork
  -Fix error round(int) is amigious adding (float) br=round((float)(((0xF0...

  ...bump...bump...bump and changes required by new ESP32 Packages

  2023-09-06
  -Bump Version for Testing Libraries and IDE Updates

  2023-07-20
  -Add "-S3" to the (Testing) Boot Screeen Version String if ESP32-S3 is used
  
  2023-07-02
  -Release to Stable

  2023-04-27
  -Cosmetics

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

  2023-01-08
  -Add Boolean "runsTesting"

  2022-12-09..2023-01-07
  -Add more "hasXX"

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

  2022-11-27
  -Switch dtiv Version handling from "EEPROM" to "Preferences"

  2022-11-23
  -Removed unused Board Types

  2022-11-12..13
  -Add Support for ESP32-S3 (ESP32-S3-DevKitC-1)
  -Removed OTA Support
  -Add EEPROM Support for d.ti Boards (IDE: ESP32* Dev Module)

  2022-10-30
  ***** Release to stable 221030 ******

  2022-10-24
  -Change Picture Array logoBin from "malloc" to "normal" defined type.

  2022-10-20
  -Add randomly chosen animated ScreenSaver after Corechange

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

  2022-10-09
  ***** Release to stable 221009 ******

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

  2022-09-01
  -More usage of "dtiv"

  2022-08-26..28
  -New Command "CMDSHSYSHW" shows Hardware & Software Infos on Screen

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

  2022-08-23
  -Replace some "if (pcaAvail)" with "if (dtiv==12)"

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

  2022-07-23 
  ***** Release ***** to stable 220723 (based on 220714T)

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

  2022-07-06
  -Adding two new fonts u8g2_font_commodore64_tr and u8g2_font_8bitclassic_tf

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

  2022-06-02
  -Add Function Prototypes for C++ Compatibilty

  2022-05-21
  -Only Cosmetics

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

  2022-04-05
  -Wemos Lolin 32 Profile: #define cDelay 100 fixes MiSTer SAM issues with waitforack

  2022-04-01
  -Consolidate CMDSSCP/CMDSSCP2 and oled_showSmallCorePicture/oled_showSmallCorePictureV2

  2022-03-31
  ** Release **

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

  2022-03-19
  -Screensaver Mod, use avarage of 2x2 Pixels for the small GSC Picture

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

  2022-03-02
  -Use more PicType "NONE" (Cosmetics)

  2022-02-17
  -Change minimum SceeenSaver Intervall from 10s to 5s

  2022-02-09 
  ** Release to Stable **

  2022-02-07
  -Modified Calculation ScreenSaverLogoTime
   First Screensaver shown now after ScreenSaverLogoTime-ScreenSaverInterval+ScreenSaverInterval

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

  2022-01-05
  -Cleanup unused vars, adding some cast operators

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

  2021-12-07
  -ESP32DEV only: Adding PCA9536 availabilty check

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

  2021-11-22
  -Cleanup not needed "NA/NN" Texts

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

  2021-11-15
  -Changed Option USE_TTGOT8=USE_ESP32DEV

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

  2021-11-04/07
  -New Picture Slide-In Effects (11..14) and some effect speed adjustments

  2021-10-28
  -Adding Bool-Variable "startScreenActive"
  -Renamed function "oled_mistertext" to "oled_showStartScreen"

  2021-10-27
  -d.ti Board only: Actualize Temperature on plain boot screen if activated

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

  2021-10-20
  -Added 7 Segment Font (Font 8)

  2021-10-12
  -Release "Greyscale Mode"

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

  -- G R A Y S C A L E  E D I T I O N --

  2021-09-19
  -First Grayscale Test based on MiSTer_SSD1322_USB_Testing

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

  2021-08-07
  -New & smaller USB Icon.

  2021-08-03
  -Some of the included Logo's miss their U8X8_PROGMEM.

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

  2021-07-12
  -Combine the two separate LogoDrawing functions (usb2oled_readndrawlogo/usb2oled_readndrawlogo2) into one (usb2oled_readndrawlogo2)

  2021-07-11
  -Some more yield() fixes for ESP8266
  -Bugfix Effekt 10 (Diagonal)

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

  2021-07-09
  -Some yield() fixes for ESP8266

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

  2021-06-24
  -Changed location of the "yield()" Command which is needed for 8266 NodeMCU

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

  2021-06-18
  -BasicOTA only for ESP32 <= TESTING

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

  2021-05-22
  -Device CleanUp 

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

  2021-04-??
  -Add "Set Contrast" to the Code by "ojaksch"

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

  2021-03-07
  -Adding some Menu Effects
  -Code cleanup

  2021-03-06
  -Adding some Menu Effects
  -Code cleanup

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

  2021-02-12
  -Adding some Menu Effects

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

=====================================================================================
=====================================================================================
ToDo
-Everything I forgot

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

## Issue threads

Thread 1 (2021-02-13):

Use console port

Kitrinx, 2021-02-13:
I had a similar idea for this, to draw to a small OLED or LCD in a floating panel, however my intention was to use the integrated serial console port (mini-usb) on the front of the mister. This would allow for a small display to occupy the empty space above the micro and mini usb ports on the front of most pcb or aluminum cases. By text encoding image data, you could serially send over console or game thumbnail data this way.

venice1200, 2021-02-13:
I think you need to do an active login from an computer device to use this port?
Correct me if I am wrong.

Kitrinx, 2021-02-14:
to interact with the shell, you do, however you can still view it's output with no login. You can observe this by connecting to it with a pc and watching mister's debug output without logging in.

venice1200, 2021-02-14:
OK. But for me the USB/Arduino solution is working quite well.

Anyway,  I will close this Ticket as it's not an issue.
If you like join the discussion at https://misterfpga.org/viewtopic.php?f=9&t=1887 .

Closed 2021-02-14.

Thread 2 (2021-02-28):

Typo in MiSTer_SSD1322.ino (non SD)

ojaksch, 2021-02-28:
I'm just wiring an ESP32 and OLED. Had troubie in compiling your code, but looks like there is a typo in line 192: The closing bracket closes nothing and breaks compiling therefore. Removed and compiles ok then.

venice1200, 2021-03-01:
Hi,
you are right.
I removed previously a few lines to fix the "particle effect" but deleted a few lines too much.
Fixed it now. Thanks for pointing me out.
Cheers

venice1200, 2021-03-01:
You need to download the sketch again as added the lost lines again.

ojaksch, 2021-03-02:
Pulled and works. Nice particle effect! Thanks for sharing.
I'm going to create more XBM pictures time after time. If you're interested in I'd like to push 'em...
[ATARIXL.zip](https://github.com/venice1200/MiSTer_tty2oled/files/6067843/ATARIXL.zip)

venice1200, 2021-03-02:
>
> Pulled and works. Nice particle effect! Thanks for sharing.
> I'm going to create more XBM pictures time after time. If you're interested in I'd like to push 'em...

You are welcome.

If you are member of the MiSTer FPGA forum please add a picture of your setup if you like.
The SD Version contains some more effects which you can adopt into the Standard Version.

venice1200, 2021-03-02:
Already added and uploaded your file as ATARI800.xbm to get it working with the SD Version.

Closed 2021-03-01.

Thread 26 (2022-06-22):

Need to clear certain areas, without clearing the entire screen

Paradox, 2022-06-22:
I have been trying everything I can think of, and cannot figure out how to erase text, etc. in a certain area of the screen for purposes of redrawing just that area, as just sending new text doesn't completely overwrite the existing text, and, clearing the entire screen and rewriting everything causes blinking or flickering of the entire screen. it also might help if the "buffer" worked more like a real frame buffer, and running CMDCLS didn't also clear the buffer, but, that still wouldn't help in my case.

Paradox, 2022-06-22:
I kind of figured this out by saving the previous text and flashing it with a color of 0 before printing the new text, but, it's working in one place, and, not another, it may be something I'm doing wrong, but, I'll continue to work on it, if there is no better answer.

venice1200, 2022-06-22:
Which tty2oled Firmware version are you using. Are you up-to-date?
I am asking because of the different command modes.

V2: https://github.com/venice1200/MiSTer_tty2oled/wiki/Command_v2
V1: https://github.com/venice1200/MiSTer_tty2oled/wiki/Command

Command Mode V2 is for Greyscale, V1 is the older Mono-Color Version.

Paradox, 2022-06-22:
I just looked again, and, it seems I typoed one of the vars... checking to see if it works, now, but, it would be nice to be able to do it, in a way that didn't flash the text.

Paradox, 2022-06-22:
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

As far as I know, V2 but, I fixed my typo, and, it works, but, of course, it blinks the text.

venice1200, 2022-06-22:
But you are on the right way overwriting the old text with an saved version. Thats what I do as well is such cases.
But you can do this hidden (without screen refresh), if you are on the Greyscale Version, by adding 100 to the Font Number.
See https://github.com/venice1200/MiSTer_tty2oled/wiki/Command_v2#command-cmdtxt
In this case you see the result after the next update of the screen.
Example:
Clear with Screen Update: CMDCLS
Write Text with Screen Update: CMDTXT,3,15,0,0,40,Test
Hidden Overwrite without Screen Update: CMDTXT,103,0,0,0,40,Test
Write new Text with Screen Update: CMDTXT,3,15,0,0,40,Toast
There are some more Command with hidden functionalities.

The second way is to use a filled Rectangle.
See: https://github.com/venice1200/MiSTer_tty2oled/wiki/Command_v2#command-cmdgeo
But here you need to know more or less the correct area to fill.

Hope this helps.

Paradox, 2022-06-22:
I got it to work without blinking. by writing both to the buffer and using CMDDUP

Paradox, 2022-06-23:
> Depending on your needs you can write your text and directly overwrite it hidden. Means you don't need to save your previous text. But this doesn't work for all needs.
>
> Do you publish your result/project?

I'm working on improving the TTY2OLED support (as well as many other parts of the script) for SAM.

venice1200, 2022-06-23:
Cool!

venice1200, 2022-07-06:
If you like to use other fonts double check this page:
https://github.com/olikraus/u8g2/wiki/fntlistall

I think we can add a few more.

Closed 2022-06-22.

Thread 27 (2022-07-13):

Trying to update Devkitv4

mrchrisster, 2022-07-13:
Get the following error when trying to flash my devkit:

```
ESP32 selected/detected (Wemos/Lolin/DevKit_V4).
Version of your tty2oled device is 0, but BUILDVER is 220521T.
Do you want to Update? Use Cursor or Joystick for YES=UP / NO=DOWN. Countdown: 7
------------------------------------------------------------------------
usage: esptool write_flash [-h] [--erase-all] [--flash_freq {keep,40m,26m,20m,80m}] [--flash_mode {keep,qio,qout,dio,dout}] [--flash_size FLASH_SIZE]
                           [--spi-connection SPI_CONNECTION] [--no-progress] [--verify] [--encrypt] [--encrypt-files <address> <filename> [<address> <filename> ...]]
                           [--ignore-flash-encryption-efuse-setting] [--compress | --no-compress]
                           <address> <filename> [<address> <filename> ...]
esptool write_flash: error: argument <address> <filename>: [Errno 2] No such file or directory: '/tmp/tmp.40c7QNEozo/lolin32_220521T.bin'
------------------------------------------------------------------------

Flash progress completed. Have fun!
Starting init script

Starting tty2oled.sh...
```

I can confirm that the file is not found on the server `https://www.tty2tft.de/MiSTer_tty2oled-installer/lolin32_220521T.bin`

mrchrisster, 2022-07-13:
Just noticed that I still had testing set to on in the user ini. Works fine when set to off.

ojaksch, 2022-07-14:
That was me while experimenting a different build system which failed at some point, setting a wrong version. Testing had to be named 220713T in this case. Back to old but stable build system. Sorry for any circumstances.

mrchrisster, 2022-07-14:
One other error when updating

```

Updating tools script tty2oled_cc.sh
Stopping tty2oled.sh...
Checking for device at /dev/ttyUSB0: available
Trying to identify device... HWLOLIN32 with sketch version 220507
ESP32 selected/detected (Wemos/Lolin/DevKit_V4).
Good boy, your hardware is up-to-date!
/tmp/update_tty2oled_script.sh: line 174: [: 1303: binary operator expected
Starting init script

Starting tty2oled.sh...
/root#
```

venice1200, 2022-07-14:
Do you use ssh or the cli?

mrchrisster, 2022-07-14:
Ssh. Second run through worked fine btw.

Closed 2022-07-14.

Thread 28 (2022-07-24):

Is there a way to tell the daemon to stop triggering on corename changes?

Paradox, 2022-07-24:
So we can load our own pics without killing the process, and then turn it back on, when the script exits.
If not, can we discuss adding such a feature?

Also, instead of starting another issue, I'd like to request text scrolling be added (Scrolling back and forth, as I've done in SAM, and wrap around, as I'm working on implementing, and, any other type that can be done) I imagine it would be so much easier to do in the firmware (as transitions are) than running an update timer, and doing it in the script.

venice1200, 2022-07-24:
Stopping and Starting the tty2oled Daemon Script should do the job.

But I know that SAM has the problem, and I don't know why, to (re-)start the daemon again.

An easy to implement solution, I think, can be that SAM creates a file in /tmp when tty2oled should sleep.

Means, the tty2oled Daemon works as normal but don't send data if this file exists.

Let's call the file tty2oled_sleep.

Is this a possible solution for you?

Scrolling, I will take a look and collect infos but it's nothing I like to implement actually.

Paradox, 2022-07-25:
When you start a process from another process, it becomes a child process, and can die when the parent dies, this is why we need some way to run the script without running the script, a simple named pipe or socket, or, as you suggest, even a simple file that will allow the daemon to start and stop itself, would be the best options.

Paradox, 2022-07-25:
I've tried it, works pretty well, but, I would suggest watching for MENU, and remove the file, yourself, after an amount of time, in case something goes wrong, and the file doesn't get removed on exit. Also, I exited, cleanly, but, a race condition happened, and your script didn't seem to notice that the file was gone, until I started a different core, manually, but, the good news is, it did notice, and put up the corepic.

venice1200, 2022-07-25:
The Daemon is waiting for a change of /tmp/CORENAME.
If this change happens before you remove the sleep file nothing happens.

So please try to remove the file at first, wait a moment, and then do what you need to get the user back to the MENU.

Paradox, 2022-07-25:
There is no good way to trigger the menu change, after removing the file, that would not mess up other things, if we force a change to the menu, it kills our feature of being able to continue playing the game when the user pushes a button. The best solution would be a named pipe, I will make a PR for it.

venice1200, 2022-07-25:
It should be easy to delete the sleep file on "MENU" Corename.

No need for a Pipe.

Paradox, 2022-07-25:
I figured out why it wasn't working right, and I will submit a PR for that, instead, but, I can still submit a PR for the pipe version, if you are at all interested in seeing it.

venice1200, 2022-07-25:
Check the latest tty2oled.sh in testing
https://raw.githubusercontent.com/venice1200/MiSTer_tty2oled/main/Testing/tty2oled.sh

It contains now the logic to delete the sleepfile if the corename = "MENU" and the file exists.

venice1200, 2022-07-25:
> I figured out why it wasn't working right, and I will submit a PR for that, instead.

If there is something wrong tell/show me.

Paradox, 2022-07-25:
PR submitted The problem is, once the inotifywait command is given, it blocks until a corechange happens, if the race condition is met that the corename changes, but, the sleep file still exists, it won't send the new data to the device, you almost fixed it, before I submitted mine, but, yours still didn't quite do it.

Paradox, 2022-07-25:
By the way, deleting the file, and uploading a new one, doesn't allow anyone else to know exactly what you changed...

Paradox, 2022-07-26:
checking to see if MiSTer is at the menu, but the sleep file exists, so, delete the file and go on.

venice1200, 2022-07-26:
I need ask again as I don't understand the command.

What does the command
if [ "$newcore"]; then
as there is not test operator.

Paradox, 2022-07-27:
Just so you know you don't have to explicitly initialize variables although it is good practice and even though I'm on my phone I went ahead and submitted the changes that initializes both of the variables

Paradox, 2022-07-27:
Also it doesn't need a test operator it's just checking for the existence you can put  -z at the beginning if that makes you feel better

Paradox, 2022-07-27:
PR updated

Paradox, 2022-07-27:
Sorry I did it in two commits but I'm editing on my phone and accidentally submitted when I didn't mean to

venice1200, 2022-07-27:
I will look into at the weekend.

venice1200, 2022-07-27:
Just a quick update,
the MENU Logo after booting up is no longer shown.

venice1200, 2022-07-27:
The two core variables (old/new) are initialized in the sourced system ini file.

Paradox, 2022-07-29:
Just initialize oldcore with some random data like START

venice1200, 2022-07-29:
> Just initialize oldcore with some random data like START although, I h

That helps, thx.

Can I still use **Super_Attract_Mode.sh start**?

If I do I get the follwowing on **ps ax**

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

A lot MCP's.

Paradox, 2022-07-30:
Looks normal, it produces background processes to handle triggering and CORENAME changes

Paradox, 2022-07-30:
Although in the latest at least one of those processes is gone we got rid of the inotifywait that was doing nothing for us the Python scripts were created to replace it but  it was never removed

Paradox, 2022-07-30:
I don't worry most of those processes are named pipe readers and when they are not reading or writing information they are blocked in a way that they take up less resources than the while loops that we were using before

venice1200, 2022-07-30:
Ok.

Please try https://raw.githubusercontent.com/venice1200/MiSTer_tty2oled/main/Testing/tty2oled.ven.sh
Activate debug="true" in your user ini to get some output.

venice1200, 2022-08-13:
Related to the latest PR 2022-08-13.

First, I have renamed your Script to **tty2oled.sam.sh**. Makes live easier.

Why not keeping the old strategy using "MENU"?
It was working fine or not?

venice1200, 2022-08-13:
I need to ask again, was my last "Menu" Version not working correctly?

Paradox, 2022-08-14:
It worked fine but this one will periodically time out and check to see if the file is old enough to delete, the other one would just continue to sit there as long as the file doesn't get deleted so if somebody opens htop and kills all the processes that file will not get deleted and the old version will just continue to sit there, with this one after 5 minutes it'll wake up and see that the file is too old will delete it and continue

Paradox, 2022-08-14:
There are some considerations with this, the time can be changed, so it wakes up every minute or two, instead of five, and you can change the age of the file, to a lower number, but, one issue that will need to be taken care of, is the user could change their gametimer, and, in fact, roulette mode does this, so, I think I need to add the gametimer value to the file, either, on it's own, or, a better idea might be to make the date value an expiration date (add gametimer to EPOCHSECONDS, and write that to the file, then, no matter what you set the timer to, as long as the date has passed, it is safe to assume the sleep file has been orphaned, and can be removed. I'll be right back with an updated PR.

venice1200, 2022-08-14:
Is SAM Re-Triggering the Sleepfile each Round?

Paradox, 2022-08-14:
This works better than MENU, sorry if you can't grep it, and, it also doesn't require SAM to work, if the sleep file is not there, it will just go on working like normal.

Paradox, 2022-08-14:
and, yes, it is remaking the sleep file, each time it starts a new core, but, your script doesn't need to worry about it, as long as the time contained in the sleep file is either in the future, or, in the past, your script only has the two options, no big deal. You seem to be making it out to be more complicated than it actually is.

Paradox, 2022-08-14:
As a side note, I have changed the way we display custom core pics, and, if you want to add them to the repo, just let me know, if you do, and I can remove them from our repo, and update script. Also, if you want to give the SAM_splash a different name, that fits in with your standards, just let me know, and i can make the change, necessary on our end.

venice1200, 2022-08-14:
> As a side note, I have changed the way we display custom core pics, and, if you want to add them to the repo, just let me know, if you do, and I can remove them from our repo, and update script. Also, if you want to give the SAM_splash a different name, that fits in with your standards, just let me know, and i can make the change, necessary on our end. We haven't, yet made a banner for tgfx16cd, but, if you add one before we do, and name it tgfx16cd, our script will handle it just like any other.

This note is related to which branch?

Paradox, 2022-08-14:
Yeah, the start command is broken, you should always use the proper way /media/fat/Scripts/.SuperAttract_init start (or, quickstart to skip the extra 60 second wait)

Paradox, 2022-08-14:
Start command is fixed, now.

Paradox, 2022-08-14:
I finally looked at the changes in your repo, and you completely obliterated it. like I said, before, just checking the creation date doesn't work.

Paradox, 2022-08-14:
Yeah, I'm totally lost on the pics, do I create a new rar?

venice1200, 2022-08-15:
Is there a plan from your end to use the tty2oled sleepmode in the main branch?

If yes, I would start adding just the sleepfile detection with the corresponding inotifywait command to our daemon script.

I would not add the semi-automatic sleepfile deletion functionality.
If we see that we really need such a functionality we know what we need to add.

Paradox, 2022-08-15:
I don't know what he plans on doing with main except the eventually named pipes will be Main but none of that matters for you if the sleep file exists you'll react to it if it doesn't you won't it won't make any difference whatsoever

venice1200, 2022-10-30:
I will close this issue for now as the Stable got already "Sleep" Support".

Closed 2022-10-30.

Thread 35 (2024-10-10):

Shared serial locking mechanism

wizzomafizzo, 2024-10-10:
I've been trying to work out a way to avoid the conflict between TapTo and tty2oled but I don't think there is any way to do so without some cooperation.

- All kernel level file locks don't work because root can override all of them
- Identifying by VIDPID does not work because the Arduinos and NFC boards both use the same clone USB UART chip
- Perhaps it's possible to add a serial command to the tty2oled device than can be run to probe and identify it, but this only helps TapTo not take over tty2oled devices, there's no way to add a similar mechanism to the NFC reader firmware and stop the tty2oled service interrupting them

I want to propose a shared locking mechanism, so we can notify each other when a serial device is in use.

- On boot with either service, create a /tmp/lock directory if it doesn't exist.
- When attempting to connect to a serial device create an empty lock file (/tmp/lock/ttyUSB0)
- Keep it there if the connection was successful
- Remove it on disconnection, error or service shut down

Whenever attempting to connect, check if the lock file exists already. If so, skip that device.

Does that sound ok for you?

venice1200, 2024-10-11:
Hi,
please test `S60tty2oled` from https://github.com/venice1200/MiSTer_tty2oled/tree/main/Testing with your tty2oled installtion.

I add code to write the lockfile.
If it works we can make it public.

wizzomafizzo, 2024-10-12:
@venice1200 thank you for implementing this so quickly

I think I'm still seeing a problem with the setup though

Do you have Discord or another message app? Can we please have a chat about it? Will be faster

venice1200, 2024-10-13:
It‘s just a test and not rolled out already.

Setup Problems?
With TapTo or tty2oled?
Our setup is straight forward, set the device and use it.

But as long tty2oled is started after TapTo you can run into the same problems again.
What was wrong with my solution as it was working for me perfectly.
It doesn‘t matter which device is started first.
Everything runs fine even TapTo was not connected.

No, I don‘t use chat tools.

wizzomafizzo, 2024-10-13:
The problem is that if the user has multiple serial devices plugged in, the order of their ttyUSBX assignment can change. We also cannot use the /dev/serial symlinks because the chips look identical to the OS.

My understanding is that the device path assignment in tty2oled is static, yes? So if the user has a tty2oled plugged in and an NFC reader plugged in, it's possible between power cycles that an NFC reader is given the configured device path in the tty2oled ini. So even with the lock files, in its current state, the solution will not work.

My question is can tty2oled detect if a device is a tty2oled or not? Is there a serial command available that will not cause any disruption, and respond with enough information to say yes ok this is definitely a tty2oled on the device path?

Then I can see 2 possible solutions here:

- tty2oled implements dynamic device connection as well as the lock files (which I'll also implement and respect) so that instead of hardcoding the device path, it probes the available serial devices, finds the tty2oled on the fly and uses that instead of a hardcoded path
- TapTo takes over the connection/detection of tty2oled devices and game monitoring, and hands off tty2oled updates to the tty2oled script to perform. So there is no longer a tty2oled service/daemon running alongside TapTo which can cause conflict, TapTo itself brokers all the connections and makes sure nothing is conflicting. Obviously if the user does not use TapTo, everything continues like before with the original tty2oled daemon running. In this case, there would just need to be a command available to TapTo like: `tty2oled.sh "<device path>" "<core name>" "<game?>"`

venice1200, 2024-10-13:
The tty2oled.sh daemon script can be startet from cli or any other process adding the device as the first parameter to the script.
Example: tty2oled.sh /dev/ttyUSB2

You can also send the „nullcommand“ and wait for the „ttyack“ response.
https://github.com/venice1200/MiSTer_tty2oled/wiki/Command_v2#command-cmdnull

Currently there is no dynamic detection.

But I don‘t think so complicate, if a user wants to use more then one communication device then he needs to know how to set them up.
If he change the order of his USB Connections he needs to know that the device number/path are changed.

Again, whats wrong with my solution?
It‘s not dynamic I now but it works.

venice1200, 2024-10-13:
Even I implement something dynamic, how could you make sure TapTo doesn't probe the port which is used by tty2oled?

wizzomafizzo, 2024-10-14:
It depends which solution you are talking about.

> Even I implement something dynamic, how could you make sure TapTo doesn't probe the port which is used by tty2oled if TapTo is started before tty2 oled?

Because we have also implemented the locking procedure.

> Again, whats wrong with my solution? It‘s not dynamic, I now, but it works.

That's what I was explaining in my first 2 paragraphs. It doesn't work if the user has both devices plugged in, because the paths may change during power cycles and the path is hardcoded in the user's tty2oled config.

> You can also send the „nullcommand“ and wait for the „ttyack“ response.
> https://github.com/venice1200/MiSTer_tty2oled/wiki/Command_v2#command-cmdnull

I will look at this thank you.

I'm open to suggestions if you have a better solution, but the way it works currently is not working.

venice1200, 2024-10-14:
If the user uses the same ports for TapTo and tty2oled permanently (static) the device paths should not being changed during power cycles.

If you keep this order, our both devices should work together.

Thats my setup. I have my tty2oled display connected to port no.1 of my usb hub and get ttyUSB0 assigned all the times

I think, if you have a static setup the device path numbers are assigned in the order of the usb port numbering order given by the usb hin chip.

If you change the order of the USB connections or plug something in during runtime it’s likely you get other device paths. Also on the following reboot it can be changes in the order again.
I can confirm this.

I never tried to send commands to a tty2oled display with an uninitialized port on MiSTer side.
Means i don‘t know the result if you use the „nullcommand“ before the port setup is done.

The port-init is done from the tty2oled daemon script „tty2oled.sh“.

Let see your results.

wizzomafizzo, 2024-10-14:
Ok understood. I'm sorry, but "the user shouldn't ever change how the ports are plugged in" is not an acceptable user experience for me even if that does work. It also wasn't my intention to give you any extra work you don't want to do. I will see what I can work out. Thanks for your time, venice

venice1200, 2024-10-14:
To have a dynamic setup will be fine.
But I think it’s not so easy to do.

RealLarry had the idea to add a tool which checks all available port and assign them based on the results.
This has to be done before all other add-ons are started.

But then you need to (re-) initalize the ports as needed before you can check the attached devices.

Maybe we can start and write a small script which returns the device path and the attached device so the user can use this for his setup.

How do you detect the cardreader?

venice1200, 2024-10-16:
What about the Idea to use a blacklist at your end?

Add device path's (tty2*) which should not probe'ed to to this list.

Advantage:
TapTo is still dynamic but doesn't harm the tty2* devices.

Dis-Advantage:
If someone removes a tty device it can be that TapTo can't probe his (new) device path as it's blacklisted.

I still thinking about a clever solution which works for every device and in every boot order.

Maybe we really need the broker script which checks all available devices before the start of the device function himself.

venice1200, 2024-10-16:
Gimme a short "hello" if you still read here.

wizzomafizzo, 2024-10-16:
Hello. I did an experiment a couple of days ago and it was pretty simple for me to auto-detect and initialise the tty2oled from TapTo and treat it as a "reader". I'm interested in doing this now so that I can potentially add screens as a capability of a reader. So in this case I would probably just disabled the tty2oled service while TapTo is running, to avoid conflict

I'm not sure how this broker script will work though. Would you mind explaining in some more detail?

venice1200, 2024-10-16:
How did you initialize the device for using the tty2oled screen?
Using stty or something different?

Using the tty2oled commands you can show text, limited graphics and pictures like you want.

Broker:
As I wrote before "i think" if we use something dynamic and lock files it fails as one of our devices will be started at first. This device can confuse the second device with his probing.

So the idea is to have a broker-script which starts first, does his device checks, get the device paths for the connected tools (TapTo, tty2oled) and writes the result to a temp file.

If this tool has done his job, TapTo and tty2oled can start (or being started by the broker), reading the detected values from temp and start their work.

Just an idea

Closed 2024-10-14.

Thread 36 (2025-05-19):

tty2oled only works when plugged into specific USB port

mdhoney, 2025-05-19:
My tty2oled only appears to work when it is plugged into a specific USB port on my USB hub.  Otherwise, running the update script gives a "not found" error.  Do I need to edit the `.ini` file to specify a particular port?  I wasn't able to find any such settings in the file.

venice1200, 2025-05-19:
Is you tty2oled working?
If yes, the the default port should fine for your hardware.
Default Port from the system ini file.
TTYDEV="/dev/ttyUSB0"

See here more informations about the tty2oled in file(s).
https://github.com/venice1200/MiSTer_tty2oled/wiki/Installation#ini-file

Please provide some more information.
Especially about the used hardware.

This is the link for troubleshooting
https://github.com/venice1200/MiSTer_tty2oled/wiki/Troubleshooting

mdhoney, 2025-05-19:
> Hi!

Hi, thanks for your reply!

> Is you tty2oled working?

Yes, it is (provided I plug it into a particular one of the USB ports).

> Default Port from the system ini file. TTYDEV="/dev/ttyUSB0"

If I ssh into my MiSTer and do an `ls` in `/dev`, the only ttyUSB device I see is `/dev/ttyUSB0`.

> Please provide some more information. Especially about the used hardware.

Using a [MiSTER Pi](https://retroremake.co/pages/store) with [MiSTer USB Hub](https://retroremake.co/products/mister-usb-hub). All other devices I've attached to it (Wi-Fi dongle, mouse, keyboard etc.) work fine.
Can you think of a reason why it might work on one USB port but not another?

venice1200, 2025-05-20:
I habe an idea but i need you to provide the output of

dmesg | grep tty

from the MiSTer’s command line once after the tty2oled is working and another one after the update says „not found“.

mdhoney, 2025-05-20:
Sure, here you go.

tty2oled working:
```
[    1.114292] printk: console [ttyS0] disabled
[    1.114449] ffc02000.serial0: ttyS0 at MMIO 0xffc02000 (irq = 48, base_baud = 6250000) is a 16550A
[    1.114605] printk: console [ttyS0] enabled
[    1.115540] ffc03000.serial1: ttyS1 at MMIO 0xffc03000 (irq = 49, base_baud = 6250000) is a 16550A
[    1.975913] usb 1-1.3: cp210x converter now attached to ttyUSB0
```

Plugging into an "unusable" port and running _update_tty2oled_ gives the following error message:

Checking for device at /dev/ttyUSB0: Could not connect to interface. **Please check USB connection and run script again.**
```
[    1.975913] usb 1-1.3: cp210x converter now attached to ttyUSB0
[ 1224.208817] cp210x ttyUSB0: cp210x converter now disconnected from ttyUSB0
```

Connecting to an "unusable" port results in the same output:
```
[    1.975913] usb 1-1.3: cp210x converter now attached to ttyUSB0
[ 1224.208817] cp210x ttyUSB0: cp210x converter now disconnected from ttyUSB0
```

Not sure how to determine the MCU version.  Is there a way to do it in software?  I opened up the case but all I can see is the Wi-Fi/Bluetooth chip:
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
I will ask the guy who I bought it from.

Thanks again for all your help!

venice1200, 2025-05-20:
Thanks
for whatever reason the display seems to have problem on reconnections.
How old is it?
The display uses an ESP8266 (NodeMCU) not the preferred ESP32 which much faster.

Can you again provide logs from „update“ and „unusable“ without grepping the output.

Just type
dmesg
after update.

Unusable:
From that what I know, when you use another usb port it is possible that the display get another ttyUSB Device Number.
But this should only happen if another ttyUSB device is connected to the MiSTer.
From the logs above I see only one device.

What happens when you start your MiSTer with the display connected to the unusable port?
Does it work?

mdhoney, 2025-05-20:
Hi again,

The display looks like this:
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

And when the tty2oled update script correctly finds the device I get the following info:
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

When it doesn't find the device, here is the dmesg output:
```
[31936.295679] MiSTer_fb 22000000.MiSTer_fb: width = 1920, height = 1080, format=8888
[31936.353762] input: MiSTer virtual input as /devices/virtual/input/input271
[31958.793552] usb 1-1.3: USB disconnect, device number 3
[31958.794417] cp210x ttyUSB0: cp210x converter now disconnected from ttyUSB0
[31958.794514] cp210x 1-1.3:1.0: device disconnected
[31969.406730] MiSTer_fb 22000000.MiSTer_fb: width = 1920, height = 1080, format=8888
[31970.126098] input: MiSTer virtual input as /devices/virtual/input/input272
[31977.716830] MiSTer_fb 22000000.MiSTer_fb: width = 1920, height = 1080, format=8888
```

> What happens when you start your MiSTer with the display connected to the unusable port?
> Does it work?

No.  It just keeps displaying the default "tty2oled" logo.

I'm wondering if it also could be a problem with my Micro-USB cable... Can you recommend any particular ones?

venice1200, 2025-05-20:
Is the „unusable“ port working with other usb devices?
Maybe the port is damaged and provides only power.
Btw. the hub from link above, the lower two ports are only sourcing power if i am correct.

And just for my understanding, if you use a „good“ port, does the update detects the tty2oled device every time correctly and is it working fine after the update has finished?

The update process reboots the display before it tries to detect the correct type for patching.
Maybe there is something going wrong.
I need to search my hardware to find a similar board and I will check this.

mdhoney, 2025-05-20:
> Is the „unusable“ port working with other usb devices? Maybe the port is damaged and provides only power. Btw. the hub from link above, the lower two ports named pwr1 and pwr2 are only sourcing power, if i am correct.

You are correct!  And I am an idiot... now that I've looked more closely, those two ports I was trying to use both say "USB Power".

So that explains it.  No USB data on those ports - when using any of the other ones tty2oled works just fine.  Thanks for working through this with me!  I appreciate it, and thanks for creating such a cool device too :smiley:

venice1200, 2025-05-21:
So, if you like to donate send me a Postcard.
If you are member of the MiSTer Forum PM me.

https://github.com/venice1200/MiSTer_tty2oled/wiki/Cardware

Closed

mdhoney, 2025-05-22:
Sorry to reopen this.... I would love to send you a card - I am sure it will make for a nice addition to your collection.  But I can't PM you on the MiSTer Forum for some reason - is there another way to get your contact details?  Thanks.

venice1200, 2025-05-22:
If you add a comment like a general „thank you“ I am sure i can pm you.
And double check your forums communications settings.

Closed 2025-05-21.

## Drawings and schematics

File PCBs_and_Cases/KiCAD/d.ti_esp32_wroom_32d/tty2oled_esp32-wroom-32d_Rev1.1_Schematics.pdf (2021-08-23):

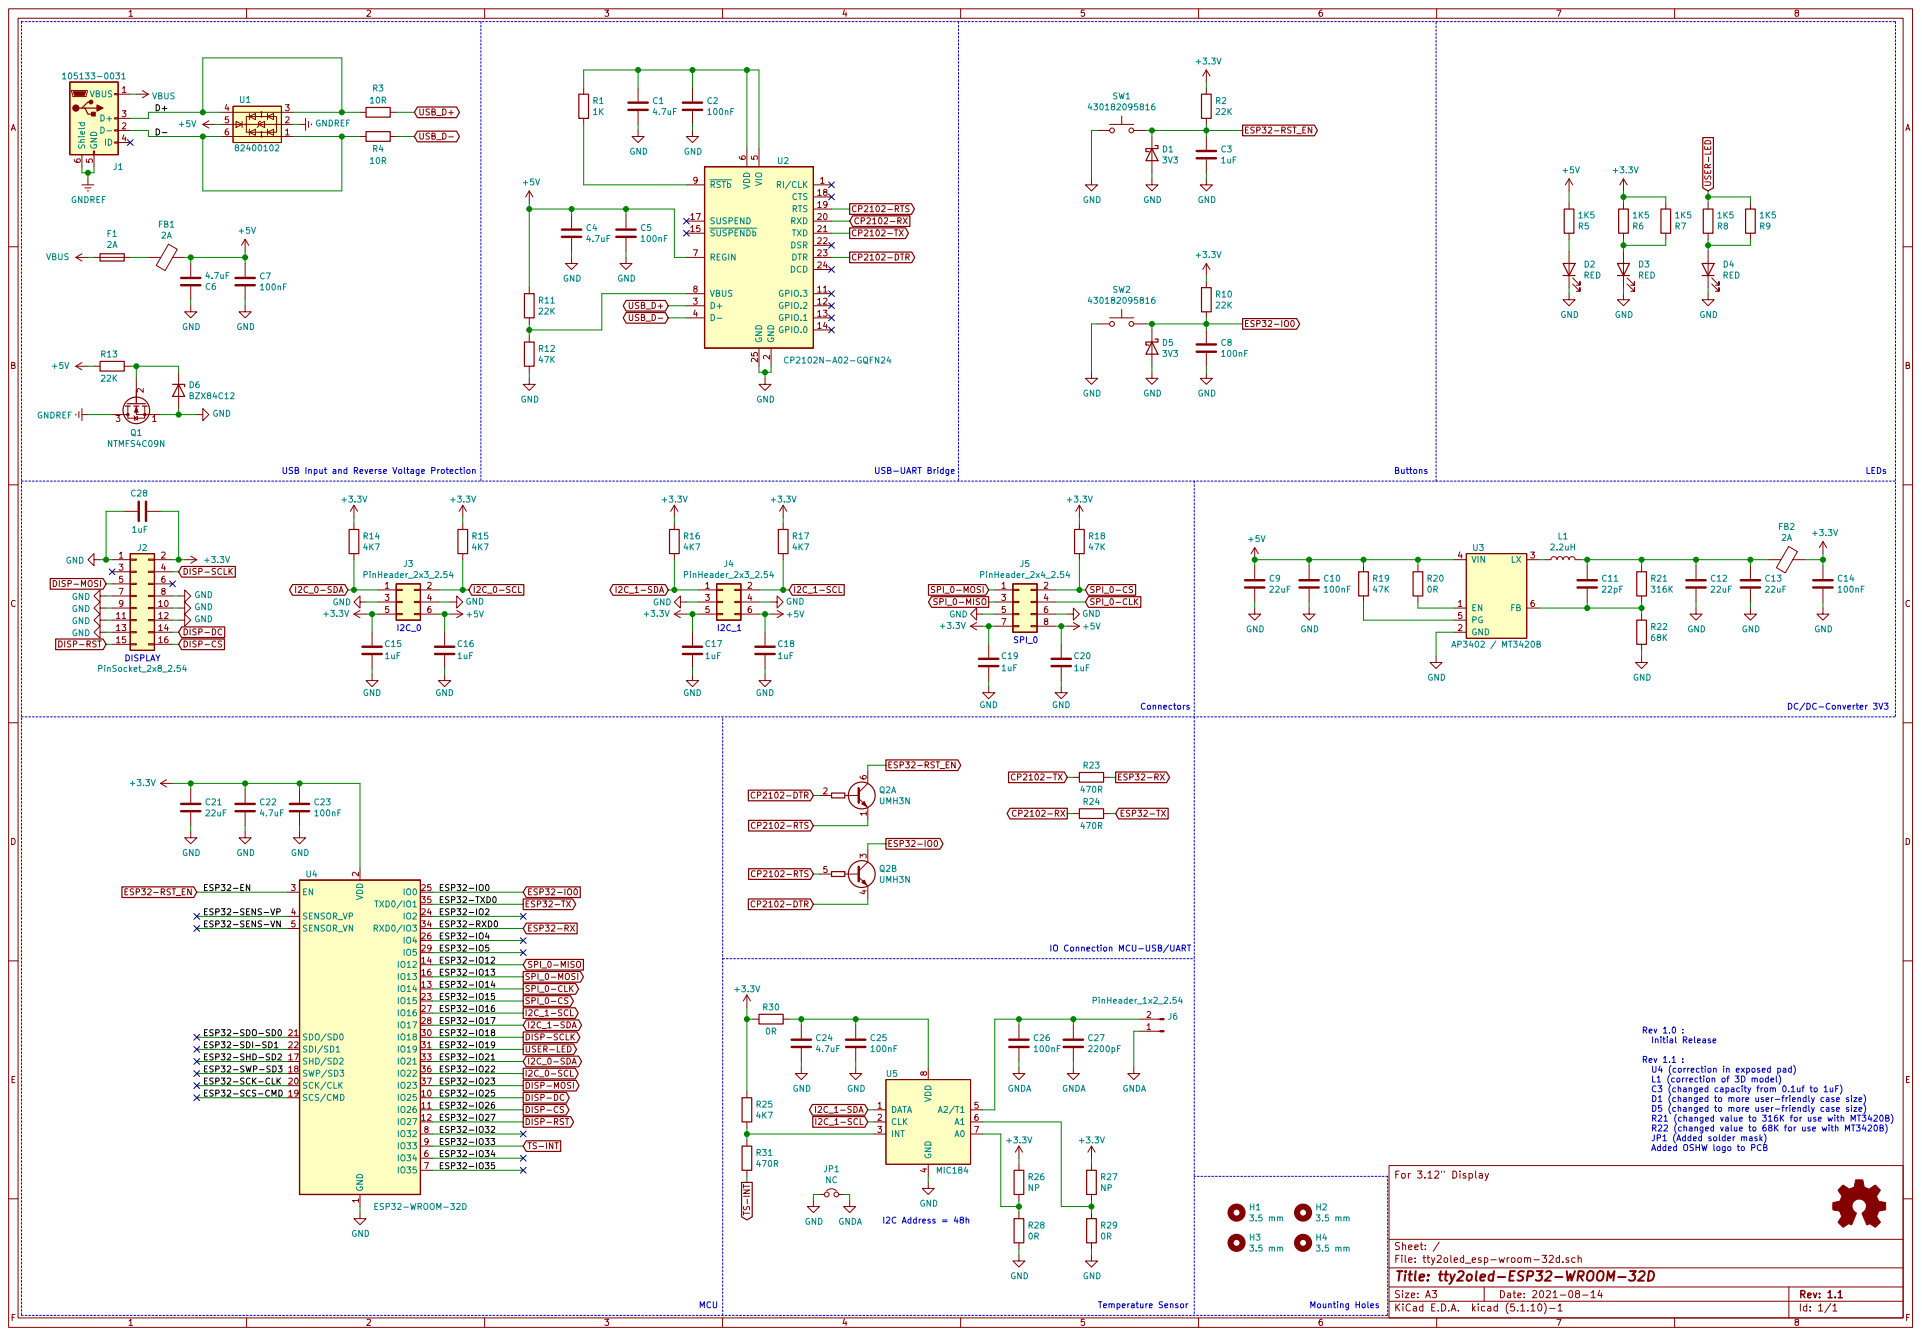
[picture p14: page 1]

2 RXD 20 TXD 21 DSR 22 DTR 23 DCD 24 GND 25 D+ 3 D- 4 VIO

2 SCK/CLK 20 SDO/SD0 21 SDI/SD1 22
ESP32-TXD0 ESP32-IO35 ESP32-IO27 ESP32-IO34 ESP32-IO33

U4 (correction in exposed pad)
L1 (correction of 3D model)
C3 (changed capacity from 0.1uf to 1uF)
D1 (changed to more user-friendly case size)
D5 (changed to more user-friendly case size)
R21 (changed value to 316K for use with MT3420B)
R22 (changed value to 68K for use with MT3420B)
JP1 (Added solder mask)
Added OSHW logo to PCB

File: tty2oled_esp-wroom-32d.sch Sheet: / For 3.12" Display

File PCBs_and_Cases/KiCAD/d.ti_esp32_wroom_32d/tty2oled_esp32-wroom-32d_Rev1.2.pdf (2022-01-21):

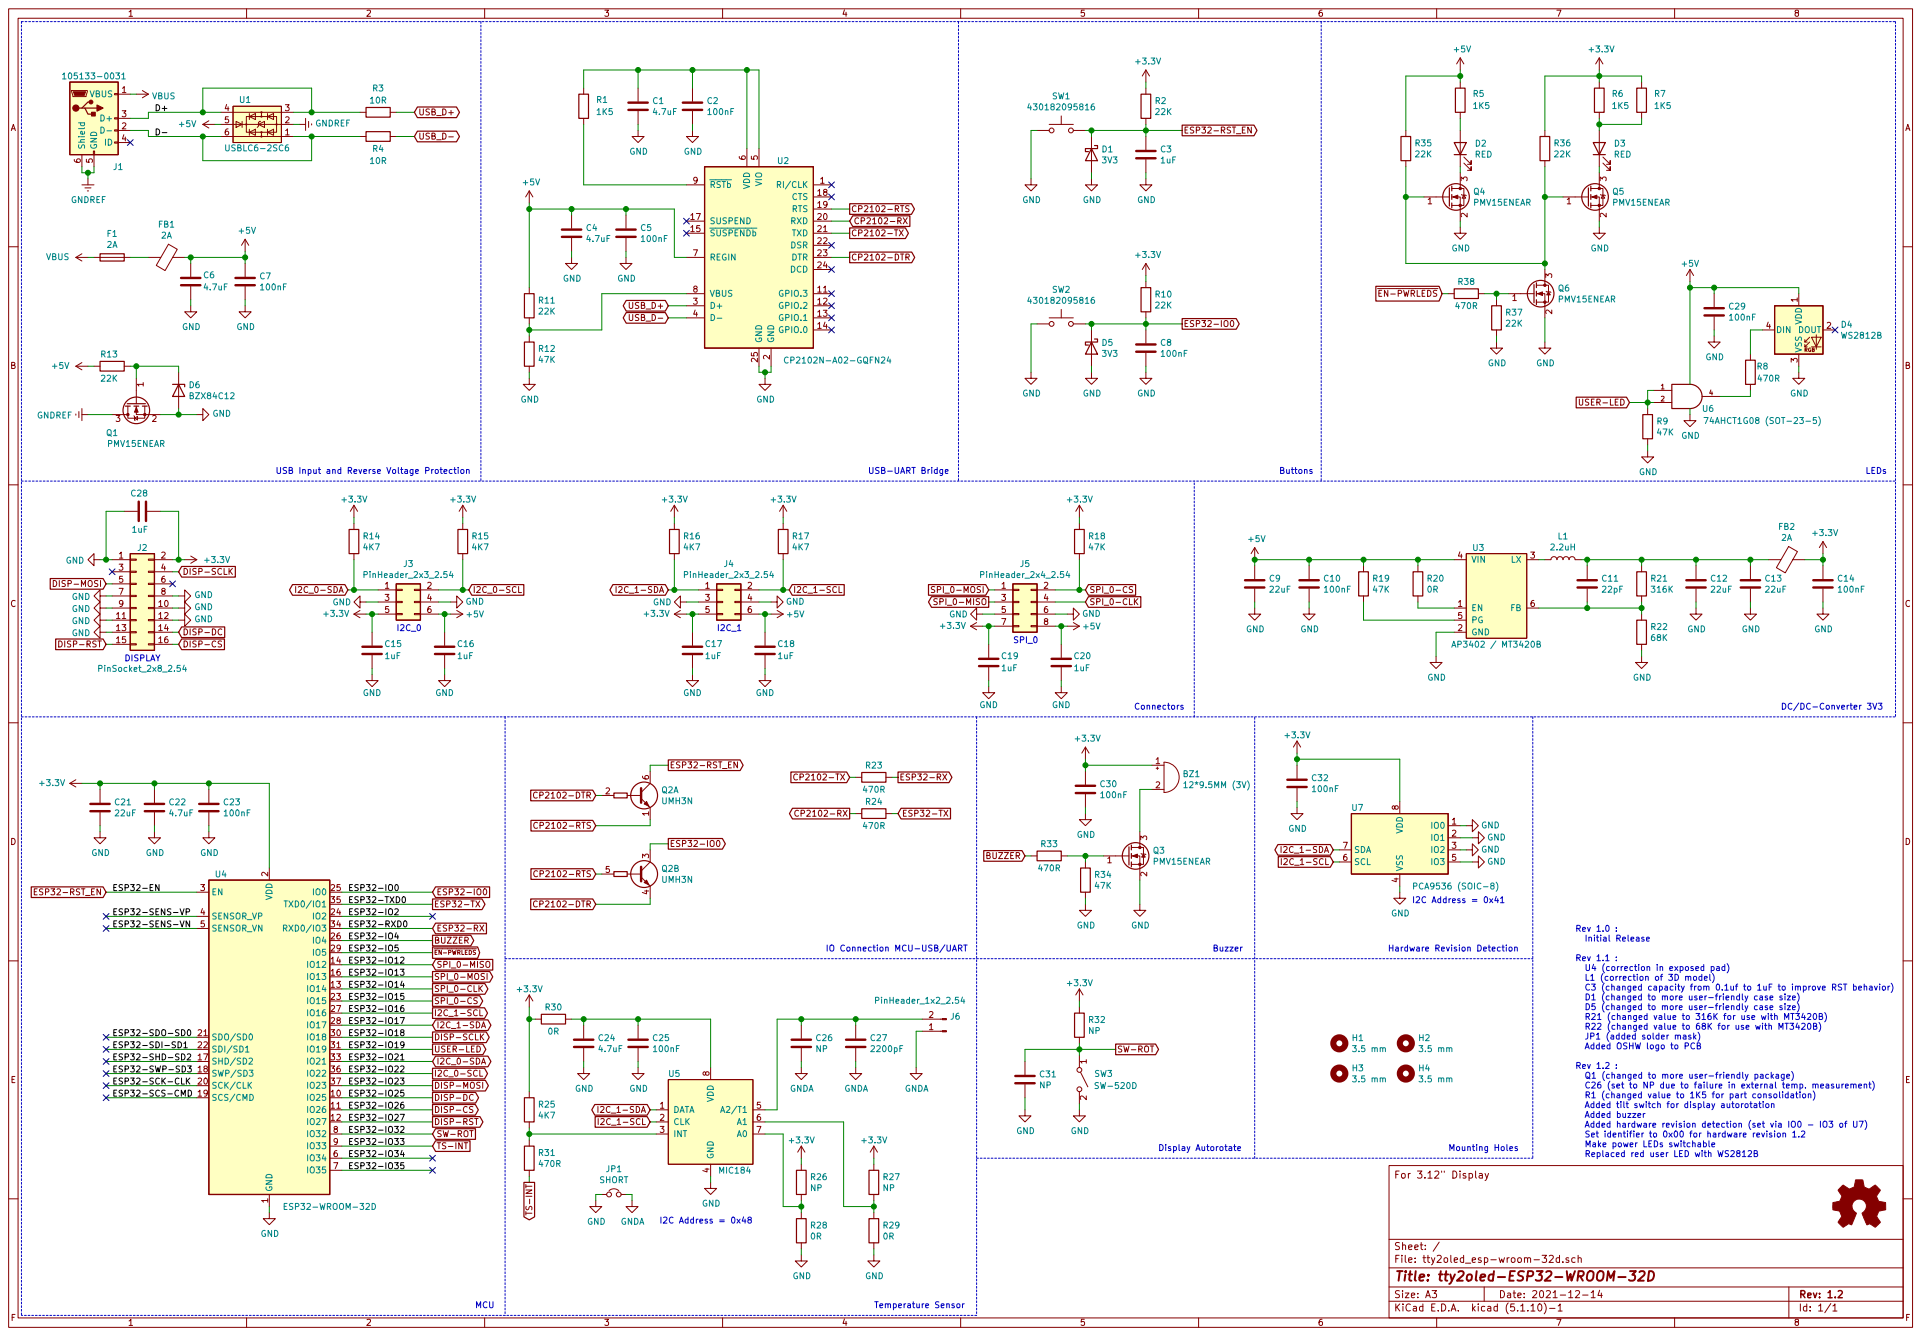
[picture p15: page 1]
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

2 SCK/CLK 20 SDO/SD0 21 SDI/SD1 22

CP2102-RTS
ESP32-IO0 DISP-MOSI DISP-RST DISP-SCLK DISP-DC
ESP32-TX

U4 (correction in exposed pad)
L1 (correction of 3D model)
C3 (changed capacity from 0.1uf to 1uF to improve RST behavior)
D1 (changed to more user-friendly case size)
D5 (changed to more user-friendly case size)
R21 (changed value to 316K for use with MT3420B)
R22 (changed value to 68K for use with MT3420B)
JP1 (added solder mask)
Added OSHW logo to PCB Rev 1.2 :

Q1 (changed to more user-friendly package)
C26 (set to NP due to failure in external temp. measurement)
R1 (changed value to 1K5 for part consolidation)
Added tilt switch for display autorotation
Added buzzer
Added hardware revision detection (set via IO0 - IO3 of U7)
Set identifier to 0x00 for hardware revision 1.2
Make power LEDs switchable

Replaced red user LED with WS2812B Mounting Holes

File: tty2oled_esp-wroom-32d.sch Sheet: / For 3.12" Display

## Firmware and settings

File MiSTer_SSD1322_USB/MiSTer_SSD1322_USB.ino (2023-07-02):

/*
  By Venice
  Get CORENAME from MiSTer via USB-Serial-TTY Device and show CORENAME related text, Pictures or Logos
  Using forked Adafruit SSD1327 Library https://github.com/adafruit/Adafruit_SSD1327 for the SSD1322

  -- G R A Y S C A L E  E D I T I O N --

  Needed libraries for the Arduino program:
  - Adafruit GFX (*)
  - U8G2 for Adafruit GFX (*)
  - Bounce2 (*) optional, needed for the tilt-sensor
  - ESP32Time (*) needed for all ESP32 Boards 
  - MIC184 needed for the MIC145 sensor on d.ti's boards, get it from: https://github.com/venice1200/MIC184_Temperature_Sensor/releases
  - SSD1322 for Adafruit GFX, download and extract it from here: https://github.com/venice1200/SSD1322_for_Adafruit_GFX/releases/latest
  (*) These Libraries can be installed using Arduino's library manager.
  See also https://github.com/venice1200/MiSTer_tty2oled/wiki/Arduino-HowTo-%28Windows%29

  QuickSelect/Copy&Paste for Arduino IDE v2.x:
  
  -ESP32-S3 Dev Module
  -ESP32 Dev Module
  -WEMOS LOLIN32
  -NodeMCU 1.0
   
  See changelog.md in Sketch folder for more details
  
  ToDo
  -Check why dtiv>=13 (Reason = POR of PCA9536) If the Power Cycle is too short the PCA9536 locks his state
  -Everything I forgot
   
  Defines?!
  I use a lot "#ifdef's...endif" to enable code for a specific MCU Type.
  USE_ESP32S3DEV   An ESP32-S3 is used with the Arduino IDE Profile "ESP32-S3 Dev Module".
  USE_ESP32DEV     An ESP32 is used with the Arduino IDE Profile "ESP32 Dev Module".
  USE_LOLIN32      An ESP32 is used with the Arduino IDE Profile "WEMOS LOLIN32".
  USE_NODEMCU      An ESP8266 is used with the Arduino IDE Profile  "NodeMCU 1.0 (ESP-12E Module)".
  USE_ESP32XDEV    An ESP32-S3 is used with the Arduino IDE Profile "ESP32-S3 Dev Module" OR an ESP32 is used with the Arduino IDE Profile "ESP32 Dev Module".
  ESP32X           An ESP32-S3 or ESP32 is used.
 
*/

// Set Version
#define BuildVersion "230702"                    // "T" for Testing

// Include Libraries
#include <Arduino.h>
#include <SSD1322_for_Adafruit_GFX.h>             // SSD1322 Controller Display Library https://github.com/venice1200/SSD1322_for_Adafruit_GFX
#include <U8g2_for_Adafruit_GFX.h>                // U8G2 Font Engine for Adafruit GFX  https://github.com/olikraus/U8g2_for_Adafruit_GFX
#include "bitmaps.h"                              // Some needed pictures
#include "fonts.h"                                // Some needed fonts


// ---------------------------------------------------------------------------------------------------------------------
// ------------------------------------------- Activate your Options ---------------------------------------------------
// ---------------------------------------------------------------------------------------------------------------------

// How-To...
// Comment (add "//" in front of the Option) to de-activate the Option
// Uncomment (remove "//" in front of the Option) to activate the Option

// Get Debugging Infos over Serial
//#define XDEBUG

// Uncomment for 180° StartUp Rotation (Display Connector up)
//#define XROTATE

// ---------------------------------------------------------------------------------------------------------------------
// ---------------------------------- Auto-Board-Config via Arduino IDE Board Selection --------------------------------
// ----------------------------------- Make sure the Manual-Board-Config is not active ---------------------------------
// ---------------------------------------------------------------------------------------------------------------------

#ifdef ARDUINO_ESP32S3_DEV        // Set Arduino Board to "ESP32-S3 Dev Module"
  #define USE_ESP32S3DEV          // ESP32-S3-DevKitC-1
#endif

#ifdef ARDUINO_ESP32_DEV          // Set Arduino Board to "ESP32 Dev Module"
  #define USE_ESP32DEV            // TTGO-T8, tty2oled Board by d.ti
#endif

#ifdef ARDUINO_LOLIN32            // Set Arduino Board to "WEMOS LOLIN32"
  #define USE_LOLIN32             // Wemos LOLIN32, LOLIN32, DevKit_V4
#endif

#if defined(ARDUINO_ESP8266_NODEMCU) || defined(ARDUINO_ESP8266_NODEMCU_ESP12E)  // Set Arduino Board to "NodeMCU 1.0 (ESP-12E Module)"
  #define USE_NODEMCU             // ESP8266 NodeMCU v3
#endif

// ---------------------------------------------------------------------------------------------------------------------
// ------------------------------------------------ Manual-Board-Config ------------------------------------------------
// ------------------------------------ Make sure the Auto-Board-Config is not active ----------------------------------
// ---------------------------------------------------------------------------------------------------------------------

//#define USE_ESP32S3DEV         // ESP32-S3-DevKitC-1
//#define USE_ESP32DEV           // TTGO-T8. Set Arduino Board to ESP32 Dev Module, xx MB Flash, def. Part. Schema
//#define USE_LOLIN32            // Wemos LOLIN32, LOLIN32, DevKit_V4. Set Arduino Board to "WEMOS LOLIN32"
//#define USE_NODEMCU            // ESP8266 NodeMCU v3. Set Arduino Board to NodeMCU 1.0 (ESP-12E Module)


// ---------------------------------------------------------------------------------------------------------------------
// ---------------------------------- Is the System ESP32 / ESP32-S3 based? --------------------------------------------
// ---------------------------------------------------------------------------------------------------------------------

#if defined(ESP32) || defined(ESP32S3)
  #define ESP32X
#endif

#if defined(USE_ESP32DEV) || defined(USE_ESP32S3DEV)
  #define USE_ESP32XDEV
#endif

// ---------------------------------------------------------------------------------------------------------------------
// -------------------------------------------------- Hardware-Config --------------------------------------------------
// ---------------------------------------------------------------------------------------------------------------------

// ESP32-S3
// SPI Original: CS(FSPICS0) = 10, MOSI(FSPID) = 11, SCLK(FSPICLK) = 12, MISO(FSPIQ) = 13
#ifdef USE_ESP32S3DEV
  int cDelay = 15;                 // Command Delay in ms for ACK-Handshake
  #define OLED_MOSI 1
  #define OLED_MISO 45 
  #define OLED_SCLK 39
  #define OLED_CS 18
  #define OLED_DC 17
  #define OLED_RESET 8
  #define TILT_PIN 15
  #define I2C1_SDA 37              // I2C_1-SDA
  #define I2C1_SCL 36              // I2C_1-SCL
  #define USER_LED 40              // USER_LED/WS2812B Pin on d.ti Board
  //#define USER_LED 48              // USER_LED/WS2812B Pin on ESP32-S3-DevKitC-1
  #define POWER_LED 38             // Set Pin to "1" = LED's off
  #define BUZZER 35                // Piezo Buzzer
  #define TONE_PWM_CHANNEL 0       // See: https://makeabilitylab.github.io/physcomp/esp32/tone.html
  #include <MIC184.h>              // MIC184 Library, get from https://github.com/venice1200/MIC184_Temperature_Sensor
  MIC184 tSensor;                  // Create Sensor Class
  #include <FastLED.h>             // FastLED Library, get from Library Manager
  #define NUM_WSLEDS 1             // Number of WS-LED's
  #define WS_BRIGHTNESS 50         // WS-LED Brightness
  CRGB wsleds[NUM_WSLEDS];         // Create WS-LED RGB Array
  #define PCA_POWER 48             // Switch PCA9536 on=0 and off=1 (without defining the Port as output the PCA is off)
 //SPIClass OLED_SPI(HSPI);
  SPIClass OLED_SPI(SPI);
  #include <Preferences.h>         // Needed for d.ti Board Revisions
  Preferences prefs;
#endif

// TTGO-T8/d.ti/ESP32 Dev
// OLED Pins, Tilt Pin, I2C, User-LED for d.ti Board
// using VSPI SCLK = 18, MISO = 19, MOSI = 23 and...
#ifdef USE_ESP32DEV
  int cDelay = 15;                 // Command Delay in ms for ACK-Handshake
  #define OLED_CS 26               // OLED Chip Select Pin
  #define OLED_DC 25               // OLED Data/Command Pin
  #define OLED_RESET 27            // OLED Reset Pin
  #define I2C1_SDA 17              // I2C_1-SDA
  #define I2C1_SCL 16              // I2C_1-SCL
  #define TILT_PIN 32              // Using internal PullUp
  #define USER_LED 19              // USER_LED/WS2812B
  #define POWER_LED 5              // Set Pin to "1" = LED's off
  #define BUZZER 4                 // Piezo Buzzer
  #define TONE_PWM_CHANNEL 0       // See: https://makeabilitylab.github.io/physcomp/esp32/tone.html
  #include <MIC184.h>              // MIC184 Library, get from https://github.com/venice1200/MIC184_Temperature_Sensor
  MIC184 tSensor;                  // Create Sensor Class
  #include <FastLED.h>             // FastLED Library, get from Library Manager
  #define NUM_WSLEDS 1             // Number of WS-LED's
  #define WS_BRIGHTNESS 50         // WS-LED Brightness
  CRGB wsleds[NUM_WSLEDS];         // Create WS-LED RGB Array
  #define PCA_POWER 2              // Switch PCA9536 on=0 and off=1 (without defining the Port as output the PCA is off)
  #include <Preferences.h>         // Needed for d.ti Board Revisions
  Preferences prefs;
#endif

// WEMOS LOLIN32/Devkit_V4 using VSPI SCLK = 18, MISO = 19, MOSI = 23, SS = 5 and...
#ifdef USE_LOLIN32
  int cDelay = 60;                 // Command Delay in ms for ACK-Handshake
  #define OLED_CS 5
  #define OLED_DC 16
  #define OLED_RESET 17
  #define TILT_PIN 32
#endif

// ESP8266-Board (NodeMCU v3)
#ifdef USE_NODEMCU
  int cDelay = 60;                 // Command Delay in ms for ACK-Handshake
  #define OLED_CS 15
  #define OLED_DC 4
  #define OLED_RESET 5
  #define TILT_PIN 10
  //#define TILT_PIN 16
#endif

// Create OLED Object
#ifdef USE_ESP32S3DEV
Adafruit_SSD1322 oled(256, 64, &OLED_SPI, OLED_DC, OLED_RESET, OLED_CS);
#else
// Hardware Constructor OLED Display and U8G2 Support
Adafruit_SSD1322 oled(256, 64, &SPI, OLED_DC, OLED_RESET, OLED_CS);
#endif
U8G2_FOR_ADAFRUIT_GFX u8g2;

// Tilt Sensor
#include <Bounce2.h>                     // << Extra Library, via Arduino Library Manager
#define DEBOUNCE_TIME 25                 // Debounce Time
Bounce RotationDebouncer = Bounce();     // Create Bounce class


// OTA, Reset and RTC only for ESP32
#ifdef ESP32X
  #include <ESP32Time.h>                          // Time-Library
  ESP32Time rtc;                                  // Create Real-Time-Clock Device
#endif

// -------------------------------------------------------------
// ------------------------- Variables -------------------------
// -------------------------------------------------------------

// Strings
String newCommand = "";                // Received Text, from MiSTer without "\n" currently (2021-01-11)
String prevCommand = "";
String actCorename = "No Core loaded"; // Actual Received Corename
uint8_t contrast = 5;                  // Contrast (brightness) of display, range: 0 (no contrast) to 255 (maximum)
int tEffect = 0;                       // Run this Effect
//char *newCommandChar;

bool updateDisplay = false;
bool startScreenActive = false;        
bool timeIsSet = false;                // Time was set from external ?
bool runsTesting = false;              // Testing ?
bool sendTTYACK = true;                // Sending ttyack back after Command

// Display Vars
uint16_t DispWidth, DispHeight, DispLineBytes1bpp, DispLineBytes4bpp;
int logoBytes1bpp=0;
int logoBytes4bpp=0;
//unsigned int logoBytes1bpp=0;
//unsigned int logoBytes4bpp=0;
const int hwDelay=100;                        // Delay for HWINFO Request
size_t bytesReadCount=0;
//uint8_t *logoBin;                             // <<== For malloc in Setup
uint8_t logoBin[8192];                        // fixed definition
enum picType {NONE, XBM, GSC, TXT};           // Enum Picture Type
int actPicType=NONE;
int16_t xs, ys;
uint16_t ws, hs;
const uint8_t minEffect=1, maxEffect=23;      // Min/Max Effects for Random
//const uint8_t minEffect=22, maxEffect=23;   // Min/Max Effects for TESTING

// Blinker 500ms Interval
const long interval = 500;                    // Interval for Blink (milliseconds)
bool blink = false;
bool prevblink = false;
bool blinkpos = false;                        // Pos Flanc
bool blinkneg = false;                        // Neg Flanc
unsigned long previousMillis = 0;
const int interval10 = 10;                   // Interval for Timer 10sec
const int interval30 = 30;                   // Interval for Timer 30sec
const int interval60 = 60;                   // Interval for Timer 60sec
int timer=0;                                 // Counter for Timer
bool timer10pos;                             // Positive Timer 10 sec Signal
bool timer30pos;                             // Positive Timer 30 sec Signal
bool timer60pos;                             // Positive Timer 60 sec Signal
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
void loop(void) {
  unsigned long currentMillis = millis();

  // Tilt Sensor/Auto-Rotation
  RotationDebouncer.update();                                     // Update the Bounce instance
  if (RotationDebouncer.rose()) {
#ifdef XDEBUG
    Serial.println("Tilt Rose...");
#endif
    oled.setRotation(0);
    if (actCorename.startsWith("No Core")) {
      oled_showStartScreen();
    }
    else {
      oled_drawlogo(0);
    }
  }
  if (RotationDebouncer.fell()) {
#ifdef XDEBUG
    Serial.println("Tilt Fell...");
#endif
    oled.setRotation(2);
    if (actCorename.startsWith("No Core")) {
      oled_showStartScreen();
    }
    else {
      oled_drawlogo(0);
    }
  }

  // Blinker  low--pos--high--neg--low..
  if (currentMillis - previousMillis >= interval) {         // Interval check
    previousMillis = currentMillis;                         // save the last time you blinked the LED
    blink=!blink;
  }
  blinkpos = blink & !prevblink;
  blinkneg = !blink & prevblink;
  prevblink = blink;

  // Timer
  if (blinkpos) timer++;
  timer10pos = (timer % interval10 == 0) && blinkpos;
  timer30pos = (timer % interval30 == 0) && blinkpos;
  timer60pos = (timer % interval60 == 0) && blinkpos;
  if (timer>=interval60) timer = 0;

/*
#ifdef XDEBUG
  //if (blinkpos) Serial.println("Blink-Pos");
  //if (blinkneg) Serial.println("Blink-Neg");
  if (timer10pos) Serial.println("Blink-10s");
  if (timer30pos) Serial.println("Blink-30s");
  if (timer60pos) Serial.println("Blink-60s");
  if (blinkpos) {
    Serial.printf("ScreenSaverEnabled: %s, ScreenSaverActive: %s, ", ScreenSaverEnabled ? "true" : "false", ScreenSaverActive ? "true" : "false");
    Serial.printf("ScreenSaverLogoTimer: %d, ScreenSaverTimer: %d\n", ScreenSaverLogoTimer, ScreenSaverTimer);
  }  
  if (ScreenSaverPos) Serial.println("ScreenSaverTimer");
#endif
*/

  // Get Serial Data
  if (Serial.available()) {
  	prevCommand = newCommand;                              // Save old Command
    newCommand = Serial.readStringUntil('\n');             // Read string from serial until NewLine "\n" (from MiSTer's echo command) is detected or timeout (1000ms) happens.
    updateDisplay=true;                                    // Set Update-Display Flag

#ifdef XDEBUG
    Serial.printf("\nReceived Corename or Command: %s\n", (char*)newCommand.c_str());
#endif
  }  // end serial available
    
  if (updateDisplay) {                                                                                 // Proceed only if it's allowed because of new data from serial
    if (startScreenActive && newCommand.startsWith("CMD") && !newCommand.startsWith("CMDTZONE")) {     // If any Command is processed the StartScreen isn't shown any more
      startScreenActive=false;                                                                         // This variable should prevent "side effects" with Commands and is used to disable automatic drawings
    }

    if (newCommand.endsWith("QWERTZ")) {                         // Process first Transmission after PowerOn/Reboot.
        // Do nothing, just receive one string to clear the buffer.
    }                    

    // ---------------------------------------------------
    // ---------------- C O M M A N D 's -----------------
    // ---------------------------------------------------

    // -- Test Commands --
    else if (newCommand=="CMDNULL") {                                    // NULL-Command, RunTime Test Command
        // Do nothing
    }

    else if (newCommand=="cls") {                                        // Clear Screen
      oled.clearDisplay();
      oled.display();
    }
    
    else if (newCommand=="sorg") {                                       // Start Screen
      oled_showStartScreen();
    }
    
    else if (newCommand=="bye")  {                                        // Cat Screen
      oled_drawlogo64h(sorgelig_icon64_width, sorgelig_icon64);
    }
    
    else if (newCommand=="CMDCLS") {                                        // Clear Screen with Display Update
      oled.clearDisplay();
      oled.display();
    }
    
    else if (newCommand=="CMDCLSWU") {                                      // Clear Screen without Display Update
      oled.clearDisplay();
    }

    else if (newCommand.startsWith("CMDCLST")) {                            // Clear/Fill Screen with Transition and Color
      oled_clswithtransition();
    }
    
    else if (newCommand=="CMDSORG") {                                       // Show Startscreen
      oled_showStartScreen();
    }
    
    else if (newCommand=="CMDBYE") {                                        // Show Sorgelig's Icon
      oled_drawlogo64h(sorgelig_icon64_width, sorgelig_icon64);
    }

    else if (newCommand.startsWith("CMDSECD")) {                            // Set Command Delay
      oled_setcdelay();
    }

    else if (newCommand=="CMDSHCD") {                                       // Show Command Delay
      oled_showcdelay();
    }

    else if (newCommand=="CMDSHSYSHW") {                                    // Show System HW
      oled_showSystemHardware();
    }

    else if (newCommand=="CMDHWINF") {                                      // Send HW Info
      oled_sendHardwareInfo();
    }

    else if (newCommand=="CMDTEST") {                                       // Show Test-Picture
      oled_drawlogo64h(TestPicture_width, TestPicture);
    }

    else if (newCommand=="CMDSNAM") {                                       // Show actual loaded Corename
      oled_showcorename();
    }

    else if (newCommand.startsWith("CMDSPIC")) {                            // Show actual loaded Picture with(without Transition
      oled_showpic();
      if (tEffect==-1) {                                                    // Send without Effect Parameter or Parameter = -1
        oled_drawlogo(random(minEffect,maxEffect+1));                       // ...and show them on the OLED with Transition Effect 1..MaxEffect
      } 
      else {                                                                // Send with Effect "CMDSPIC,15"
        oled_drawlogo(tEffect);
      }
    }

    else if (newCommand=="CMDSSCP") {                                       // Show actual loaded Core Picture but in 1/4 size
      oled_showSmallCorePicture(64,16);
    }

    else if (newCommand=="CMDDOFF") {                                       // Switch Display Off
      oled_displayoff();
    }

    else if (newCommand=="CMDDON") {                                        // Switch Display On
      oled_displayon();
    }

    else if (newCommand=="CMDDUPD") {                                       // Update Display Content
      oled_updatedisplay();
    }

    else if (newCommand.startsWith("CMDTXT")) {                             // Command from Serial to write Text
      oled_readnwritetext();                                                // Read and Write Text
    }
    
    else if (newCommand.startsWith("CMDGEO")) {                             // Command from Serial to draw geometrics
      oled_readndrawgeo();                                                  // Read and Draw Geometrics
    }

    else if (newCommand.startsWith("CMDAPD")) {                             // Command from Serial to receive Picture Data via USB Serial from the MiSTer
      oled_readlogo();                                                      // Receive Picture Data... 
    }

    else if (newCommand.startsWith("CMDCOR")) {                             // Command from Serial to receive Picture Data via USB Serial from the MiSTer
      if (oled_readlogo()==1) {                                             // Receive Picture Data... 
        if (tEffect==-1) {                                                  // Send without Effect Parameter or with Effect Parameter -1
          oled_drawlogo(random(minEffect,maxEffect+1));                     // ...and show them on the OLED with Transition Effect 1..MaxEffect
        } 
        else {                                                              // Send with Effect "CMDCOR,llander,15"
          oled_drawlogo(tEffect);
        }
      }
    }

    else if (newCommand.startsWith("CMDSETTIME,")) {                        // Set date and time but only for ESP32 RTC
      oled_setTime();
    }

    else if (newCommand.startsWith("CMDCON")) {                            // Command from Serial to receive Contrast-Level Data from the MiSTer
      oled_readnsetcontrast();                                             // Read and Set contrast                                   
    }
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

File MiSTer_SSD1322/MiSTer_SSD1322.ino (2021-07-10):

/*
  By Venice
  Get CORENAME from MiSTer via Serial TTY Device and show CORENAME related text, Pictures or Logos
  Using the universal 8bit Graphics Library (https://github.com/olikraus/u8g2/)

  Problem: 
  Sometimes after Power-On "MENU" is written instead of the logo shown.
  So i added an "first transmission" without doing anything.
*/

#include <Arduino.h>
#include <U8g2lib.h>    // Display Library
#include "logo.h"       // The Pics in XMB Format

/*
#ifdef U8X8_HAVE_HW_SPI
#include <SPI.h>
#endif
#ifdef U8X8_HAVE_HW_I2C
#include <Wire.h>
#endif
*/

// ------------ Objects -----------------
// Display Constructor HW-SPI ESP32-Board (Lolin32) 180° Rotation => U8G2_R2
U8G2_SSD1322_NHD_256X64_F_4W_HW_SPI u8g2(U8G2_R2, /* cs=*/ 12, /* dc=*/ 13, /* reset=*/ 14);  // Enable U8G2_16BIT in u8g2.h <= !! W I C H T I G !!

// Display Constructor HW-SPI Lolin32 0° Rotation => U8G2_R0
//U8G2_SSD1322_NHD_256X64_F_4W_HW_SPI u8g2(U8G2_R0, /* cs=*/ 12, /* dc=*/ 13, /* reset=*/ 14);  // Enable U8G2_16BIT in u8g2.h <= !! W I C H T I G !!

// Display Constructor HW-SPI Mighty Core ATMega 1284 0° Rotation => U8G2_R0
//U8G2_SSD1322_NHD_256X64_F_4W_HW_SPI u8g2(U8G2_R0, /* cs=*/ 17, /* dc=*/ 16, /* reset=*/ 18);  // Enable U8G2_16BIT in u8g2.h <= !! W I C H T I G !!

// ------------ Variables ----------------
// For Particle effect
const int logoBytes = 2048; // 0..2047
int logoByte;
unsigned char logoByteValue;

// Strings
String newCore = "";             // Received Text, from MiSTer without "\n\r" currently (2021-01-11)
String oldCore = "";             // Buffer String for Text change detection
char newCoreArray[30]="";        // Array of char needed for some functions, see below "newCore.toCharArray"

// Display Vars
u8g2_uint_t DispWidth, DispHeight;

// ================ SETUP ==================
void setup(void) {
  // Init Serial
  //Serial.begin(9600);              // 9600 for MiSTer ttyUSBx Device FTDI Chip or manual set Speed
  Serial.begin(57600);           // 57600 Common Modem Speed :-)
  //Serial.begin(115200);          // 115200 for MiSTer ttyUSBx Device CP2102 Chip on ESP32
  Serial.flush();
  
  //Init Random Generator
  randomSeed(analogRead(34));

  // Init Display
  u8g2.begin();
  u8g2.setFont(u8g2_font_tenfatguys_tr);     // 10 Pixel Font
  u8g2.setDrawColor(1);  // White (Standard)
  u8g2.setFontPosTop();
  u8g2.setFontDirection(0);

  //u8g2.setFontRefHeightExtendedText();
  //u8g2.setFont(u8g2_font_tenthinguys_tf);
  //u8g2.setFont(u8g2_font_6x10_tf);
  //u8g2.setFont(u8g2_font_ncenB08_tr);
  //u8g2.setDrawColor(0); // Black

  // Get Display Dimensions
  DispWidth = u8g2.getDisplayWidth();
  DispHeight = u8g2.getDisplayHeight();
  
  // Startup with Some Text
  oled_mistertext();
}

// ================ MAIN LOOP ===================
void loop(void) {

  if (Serial.available()) {
    newCore = Serial.readStringUntil('\n');                  // Read string from serial until NewLine "\n" (from MiSTer's echo command) is detected or timeout (1000ms) happens.
  }  // end serial available
    
  if (newCore!=oldCore) {                                    // Proceed only if Core Name changed
    // Many if an elses as switch/case is not working (maybe later with an array).

    // -- First Transmission --
    if (newCore.endsWith("QWERTZ")) {                        // TESTING: Process first Transmission after PowerOn/Reboot.
        // Do nothing, just receive one string to clear the buffer.
    }                    
    
    // -- Menu Core --
    else if (newCore=="MENU")         oled_misterlogo();     // TESTING! Sometimes after Power On "MENU" is written instead of the logo shown. Maybe one character in the serial buffer?
    
    // -- Arcade Cores --
    else if (newCore=="asteroid")     oled_drawlogo64h(asteroids_logo_width, asteroids_logo);
    else if (newCore=="atetris")      oled_drawlogo64h(atetris_logo_width, atetris_logo);
    else if (newCore=="atetrisc")     oled_drawlogo64h(atetris_logo_width, atetris_logo);
    else if (newCore=="centiped")     oled_drawlogo64h(centiped3_logo_width, centiped3_logo);
    else if (newCore=="centiped3")    oled_drawlogo64h(centiped3_logo_width, centiped3_logo);
    else if (newCore=="dkong")        oled_drawlogo64h(dkong_logo_width, dkong_logo);
    else if (newCore=="ckongdks")     oled_drawlogo64h(dkong_logo_width, dkong_logo);
    else if (newCore=="dkong3")       oled_drawlogo64h(dkong3_logo_width, dkong3_logo);
    else if (newCore=="dkong3b")      oled_drawlogo64h(dkong3_logo_width, dkong3_logo);
    else if (newCore=="frogger")      oled_drawlogo64h(frogger_logo_width, frogger_logo);
    else if (newCore=="llander")      oled_drawlogo64h(llander_logo_width, llander_logo);
    else if (newCore=="mooncrgx")     oled_drawlogo64h(mooncrgx_logo_width, mooncrgx_logo);
    else if (newCore=="mpatrol")      oled_drawlogo64h(mpatrol_logo_width, mpatrol_logo);
    else if (newCore=="pong")         oled_drawlogo64h(pong_logo_width, pong_logo);
    else if (newCore=="pooyan")       oled_drawlogo64h(pooyan_logo_width, pooyan_logo);
    // else if (newCore=="pooyan")    oled_drawlogo64h(pooyan_alt_logo_width, pooyan_alt_logo);
    else if (newCore=="popeye")       oled_drawlogo64h(popeye_logo_width, popeye_logo);
    else if (newCore=="sbrkout")      oled_drawlogo64h(sbrkout_logo_width, sbrkout_logo);
    else if (newCore=="zaxxon")       oled_drawlogo64h(zaxxon_logo_width, zaxxon_logo);

    // -- Computer Cores --
    else if (newCore=="AcornAtom")    oled_drawlogo64h(acornatom_logo_width, acornatom_logo);
    else if (newCore=="AO486")        oled_drawlogo64h(ao486_logo_width, ao486_logo);
    else if (newCore=="APPLE-I")      oled_drawlogo64h(apple_logo_width, apple_logo);
    else if (newCore=="Apple-II")     oled_drawlogo64h(apple2_logo_width, apple2_logo);
    else if (newCore=="ARCHIE")       oled_drawlogo64h(archimedes_logo_width, archimedes_logo);
    else if (newCore=="AtariST")      oled_drawlogo64h(atarist_logo_width, atarist_logo);
    else if (newCore=="ATARI800")     oled_drawlogo64h(atarixl_logo_width, atarixl_logo);
    else if (newCore=="C64")          oled_drawlogo64h(c64_logo_width, c64_logo);
    else if (newCore=="Minimig")      oled_drawlogo64h(amiga_logo_width, amiga_logo);
    else if (newCore=="MSX")          oled_drawlogo64h(msx_logo_width, msx_logo);
    else if (newCore=="PET2001")      oled_drawlogo64h(pet2001_logo_width, pet2001_logo);
    else if (newCore=="VIC20")        oled_drawlogo64h(vic20_logo_width, vic20_logo);
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

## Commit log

2021-02-08 Update README.md
    Added SD Version Technical Note (SPI Interface)
2021-02-11 Update Particle Effect
    Now the Particel Effects works correctly
    [MiSTer_SSD1322_SD.ino]
2021-02-11 Update Particel Effect
    No the Particle Effect works correctly
    [MiSTer_SSD1322.ino]
2021-03-01 Fixed Compiler issue
    I fixed previously the "particle" effect and removed "if (logoByteValue > 0)" but deleted then a few lines too much. Sorry.
    [MiSTer_SSD1322.ino]
2021-03-14 Update SD Version from SPI to SD Bus usage
2021-03-26 New working mode: pictures by usb connection (see MiSTer_SSD1322_USB), new tested board: ESP8266/NodeMCU
2021-03-26 KiCAD sources and Gerbers (veryfied, but untested for now)
    [tty2oled-esp32-sd.kicad_pcb, tty2oled-esp32-sd.sch, tty2oled-esp8266.kicad_pcb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]
2021-03-28 KiCAD: GNDs added, files renamed
    [tty2oled_esp32-ttgo-t8-v1.7.1_sd.kicad_pcb, tty2oled_esp32-ttgo-t8-v1.7.1_sd.sch, tty2oled_esp8266-NodeMCU_v3.kicad_pcb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]
2021-03-28 Readme added to Gerbers
2021-03-29 GND was missing in KiCAD/Gerbers
    [tty2oled_esp32-ttgo-t8-v1.7.1_sd.kicad_pcb, tty2oled_esp8266-NodeMCU_v3.kicad_pcb]
2021-03-29 Upload Board Pictures
2021-03-29 Board ESP8266 NodeMCU v3 added
2021-04-04 KiCAD, Gerbers & Picture of ESP32-DevKitC_v4
    [tty2oled_esp32-DevKitC_v4.kicad_pcb, tty2oled_esp32-DevKitC_v4.sch]
2021-04-04 Delete MiSTer_SSD1322_USB_ojaksch directory
    No longer needed.
    [MiSTer_SSD1322_USB.ino, logo.h]
2021-04-16 Fixed shortcut in esp32-DevKitC_v4 design
    [tty2oled_esp32-DevKitC_v4.kicad_pcb]
2021-05-08 Make the TTGO default Board
2021-05-10 Documentation of MOUNTRO
2021-05-15 Non working gfx effects for ESP8266 fixed
    [MiSTer_SSD1322_USB.ino]
2021-05-17 Arduino HowTo
2021-05-19 Case for 3.12in SSD1322 high-stacked
2021-05-26 ESP32-DevKitC removed
    [tty2oled_esp32-DevKitC_v4.kicad_pcb, tty2oled_esp32-DevKitC_v4.sch]
2021-05-27 ESP32-DevKitC removed, Lolin32 added
    [tty2oled_esp32-Lolin32.kicad_pcb, tty2oled_esp32-Lolin32.sch, tty2oled_esp32-ttgo-t8-v1.7.1_sd.kicad_pcb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]
2021-05-27 Silkscreen fixed
    [tty2oled_esp32-Lolin32.kicad_pcb, tty2oled_esp32-ttgo-t8-v1.7.1_sd.kicad_pcb, tty2oled_esp8266-NodeMCU_v3.kicad_pcb]
2021-06-15 Fixed Connection Schemes ESP32, rework of DevKitC
    [tty2oled_esp32-DevKitC_v4.kicad_pcb, tty2oled_esp32-DevKitC_v4.sch]
2021-06-19 Fixed pin 19, was not supposed to be grounded on drawing
2021-06-19 Fixed pin 19 to match connection scheme
2021-06-19 Connection Scheme for New Haven Display (20 pin board)
2021-06-21 Rework of Lolin32 PCB. 0201 Pads were a bad idea.
    [tty2oled_esp32-Lolin32.kicad_pcb]
2021-06-22 Added american version of certain pictures (Sega Genesis, Sega CD) in their own folder. Added sha1.txt for it Added variable in tty2oled.ini to enable american versions (else : rest of the world) Add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
2021-06-23 Moved current TGFX16 file to US region
2021-06-25 Update board esp8266 to v1.1
    [tty2oled_esp8266-NodeMCU_v3.kicad_pcb]
2021-06-25 Update board esp32-lolin32 to v1.1
    [tty2oled_esp32-Lolin32.kicad_pcb]
2021-06-25 Update board esp32-DevKitC to v1.1
    [tty2oled_esp32-DevKitC_v4.kicad_pcb]
2021-06-25 Update board esp32-TTGo to v1.1
    [tty2oled_esp32-ttgo-t8-v1.7.1_sd.kicad_pcb]
2021-06-25 Fixup of the Käseecke :)
    [tty2oled_esp32-Lolin32.kicad_pcb, tty2oled_esp32-ttgo-t8-v1.7.1_sd.kicad_pcb]
2021-06-25 Fixup of license esp8266
    [tty2oled_esp8266-NodeMCU_v3.kicad_pcb]
2021-06-25 PCB TTG0 shrunk by 0.8mm
    [tty2oled_esp32-ttgo-t8-v1.7.1_sd.kicad_pcb]
2021-07-07 Modified kernel with support for CH34x USB devices
2021-07-08 New pictures: Legendary Wings (Ares no tsubasa), Gun Smoke, Section Z
2021-07-10 Inserted Serial.flush()
2021-07-10 Fix of Pads for Pin#16 by 0.1mm
    [tty2oled_esp32-Lolin32.kicad_pcb]
2021-08-23 Upload BOM
2021-09-12 SPI def's for all 3 ESP's
2021-09-12 Fixup SPI def's for all 3 ESP's
2021-09-23 Update Greyscale Tilt-Switch
2021-12-03 CC und Testing Update
2021-12-18 Daemon: switch from sh to bash
2021-12-20 Remove pv, switch to rsyncy.py
2022-01-21 Adding d.ti Board Rev1.2
2022-02-17 Testing: Switch REPOSITORY_URL to Testing
2022-03-25 Update MiSTer_SSD1322_USB_Testing.ino
    Possible Response Fix
    [MiSTer_SSD1322_USB_Testing.ino]
2022-05-07 New tty2oled FW Release for ESP32 RTC Support
2022-06-08 Update installer.sh
    Changed Hardcoded Device to Device Variable
2022-06-18 Redo/Rework of PID and inotify
2022-06-25 S60: Silence the PID output
2022-07-31 Update Testing
    Make OTA Optional (XOTA), fix some typos and a bug in the debug mode.
    [MiSTer_SSD1322_USB_Testing.ino]
2022-11-23 Installer: ESP32S3 added
2022-11-23 Installer: added esp32s3 to esptool, removed obsolete HWDTIPCB0 and HWDTIPCB1
2022-11-24 Installer: correct bootloader for esp32s3
2022-11-24 Testing/Installer: modularize parts to flash for coming devices
2022-11-24 Testing/Installer: modularize parts to flash for coming devices, part 2
2023-03-02 installer/testing: autoupdate switchable and runs in background
2024-10-01 Adding ESP32 v3 Test Sketch
2025-02-07 Update Testing to ESP32 v3
2026-07-29 Update Testing
    Arduino IDE 2.3.10
    Downloadable libs/package from the Arduino IDE
    ESP32 3.3.11
    FastLed 3.10.5
    U8g2_for_Adafruit_GFX 1.8.0
    Adafruit GFX 1.12.6
    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
2026-10-10 installer.sh: recognize third-party HWGC9A01C and skip the update flow
    Refs #42
2026-10-21 installer.sh: update third-party display repo URL (renamed to mister-tty2oled-esp32)
